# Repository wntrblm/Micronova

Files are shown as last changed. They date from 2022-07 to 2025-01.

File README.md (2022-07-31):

# Winterbloom Micronova

Micronova is a small Eurorack power supply.

More details available at https://winterbloom.com/shop/micronova

## Repository layout

This repository contains the hardware design files and user guide for Micronova:

- **hardware/** contains the hardware design files for the board. These are all created using KiCAD.
- **user_guide/** contains the user's guide source files. These are written in Markdown and published using MkDocs.

## License and contributing

Micronova is open-source hardware and software, however, licensing a project like this is a little complicated. Please take a chance to review the [LICENSE](LICENSE.md) file.

We welcome contributions! Please read our [Code of Conduct](CODE_OF_CONDUCT.md) first.

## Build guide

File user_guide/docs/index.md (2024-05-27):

# Manual

[Micronova](https://winterbloom.com/shop/micronova) is a tiny but mighty Eurorack power supply. It is our love letter to the DIY ethic of the Eurorack community. It packs a lot of useful little features into a small frame and it's perfect for custom rack builds.

[TOC]

## Specifications

An illustration of Micronova

* Available [assembled](https://winterbloom.com/shop/micronova) or as a [kit](https://winterbloom.com/shop/micronova-kit)
* A tiny `100mm x 30mm` board with `M3` mounting holes
* Provides `+12V @ 1A`, `-12V @ 300mA`, and `+5V @ 500mA`
* Includes two 16-pin Eurorack power headers
* Requires a `15V to 20V` **center positive** DC power supply
* Multiple units can be daisy chained
* Reverse-polarity, over-current, and over-temperature protection
* Optional `4 HP` [front entry kit](https://winterbloom.com/shop/micronova-front-entry-kit)
* Optional [busboard](https://winterbloom.com/shop/micronova-busboard)
* [ModularGrid page](https://www.modulargrid.net/e/winterbloom-micronova)

## Getting support and help

We want you to have a wonderful experience with your power supply. If you need help or run into problems, please reach out to us. [Email] is the best way for product issues, whereas [Discord] and [GitHub][github issues] are great for getting advice and help on how to customize your module.

-   Send us [an email][email]
-   File a bug [on GitHub][github issues]
-   Reach out on the [Discord][discord]

[github issues]: https://github.com/wntrblm/Micronova/issues
[discord]: https://discord.gg/UpfqghQ
[email]: mailto:support@winterbloom.com

## Safety

Always use caution when working with electricity. While Micronova does not use mains power directly and operates on relatively low voltages (`-12V to 20V DC`), there is always risk. Never add or remove downstream devices or modify power connections while the system is powered on. Make sure to use an [appropriate AC to DC power supply](#powering-micronova) and to stay within the specified [power limits](#power-limits). Use high-quality cables and appropriately sized wires when making connections.

Micronova includes some protection features:

- It can withstand at least `30V` of reverse polarity on the power inputs
- It has transient voltage suppression on the power inputs
- It has a polyfuse to limit current during a short circuit fault
- It has independent over-current, short circuit, and over-temperature protection on each of the downstream power rails

These protection features do not avert all risks involved with operating a power supply. Micronova can still experience dangerous faults from unexpected events. Improper usage significantly increases the possibility of electric shock and fire. **Always use caution**.

## Powering Micronova

Micronova requires a `15 to 20V DC` power supply that can provide **at least** `1A`. Micronova has multiple, *interconnected* power input connections. It can be powered using one of the two DC barrel jacks or one of the two screw terminal blocks on the upper side of the board.

An illustration of Micronova highlighting the power input connection

!!! warning
    Never connect more than one upstream power supply at a time to Micronova. The multiple DC jacks and screw terminals for [daisy chaining](#daisy-chaining) multiple Micronova units to a single upstream supply. Only **one** upstream power supply should be connected. Connecting multiple upstream power supplies can result in irreversible damage, electric shock, and fire.

In most cases, you'll want to use one of the DC barrel jacks. Both Micronova and the optional [front entry panel](#front-entry-kit) have DC barrel jacks, and either of the two jacks will work. They accept plugs that have a `2.1mm` inner diameter and a `5.5mm` outer diameter. The plug should be **center positive**.

Illustration of DC barrel jack and polarity

These AC to DC power supplies are recommended if you're planning to use the DC barrel jacks:

* Mean Well [GST60A15-P1J](https://www.digikey.com/en/products/detail/mean-well-usa-inc/GST60A15-P1J/7703713) which provides `15V @ 4A (60W)`, enough to power about four Micronovas.
* Mean Well [GST40A15-P1J](https://www.digikey.com/en/products/detail/mean-well-usa-inc/GST40A15-P1J/7703705) which provides `15V @ 2.6A (40W)`, enough to power two or three Micronovas.
* Mean Well [GST25A15-P1J](https://www.digikey.com/en/products/detail/mean-well-usa-inc/GST25A15-P1J/7703649) which provides `15V @ 1.6A (25W)`, enough to power one Micronova.

All of these power supplies are rated for international use and require a separate [IEC C13 cord](https://en.wikipedia.org/wiki/IEC_60320#C13/C14_coupler) to connect to your wall outlet. These cords are incredibly common and often used with computers, monitors, and professional audio and video equipment and should be readily available from local retailers.

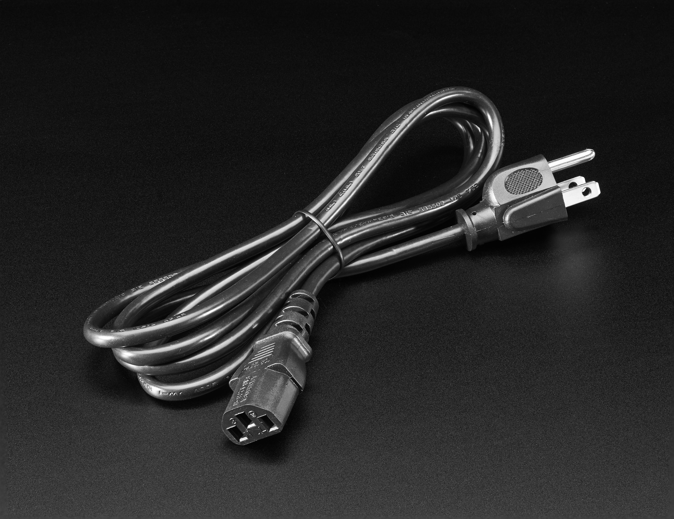
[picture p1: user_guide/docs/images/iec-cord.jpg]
Photo of an IEC C13 cord, photo from Adafruit Industries


If you need help finding a power supply or want to double check compatibility before purchasing, please [reach out to us](mailto:support@winterbloom.com).

In some advanced or unusual racks, you may want to power Micronova through its screw terminals. This might be the case if you're using a large DC power supply such as Mean Well's [RS series](https://www.digikey.com/en/products/detail/mean-well-usa-inc/RS-150-15/7706170). Ensure that the power supply's voltage output is between `15V and 20V`. You can use either of the two screw terminal blocks on the upper side of the board- just not the one labeled `switch`. Connect the power supply to Micronova using appropriately sized hook up wire (`20 or 22 AWG` stranded is recommended).

Illustration of Micronova powered using the screw terminals

## Connecting modules

Connect your modules to Micronova using either *16-to-10* pin IDC cables or *16-to-16* pin IDC cables.

<div class="columns">
    <div class="column">
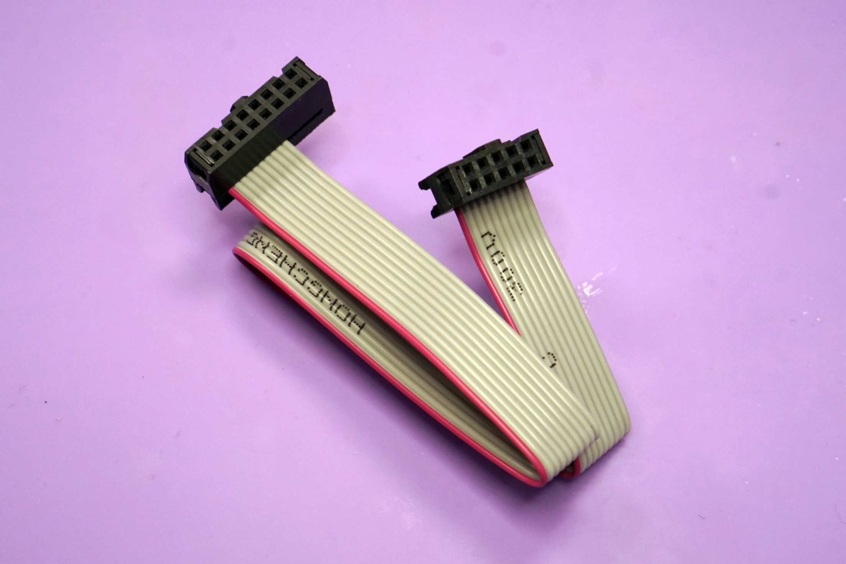
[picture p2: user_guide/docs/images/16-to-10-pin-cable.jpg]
Photo of a 16-to-10 pin IDC cable
        
    </div>
    <div class="column">
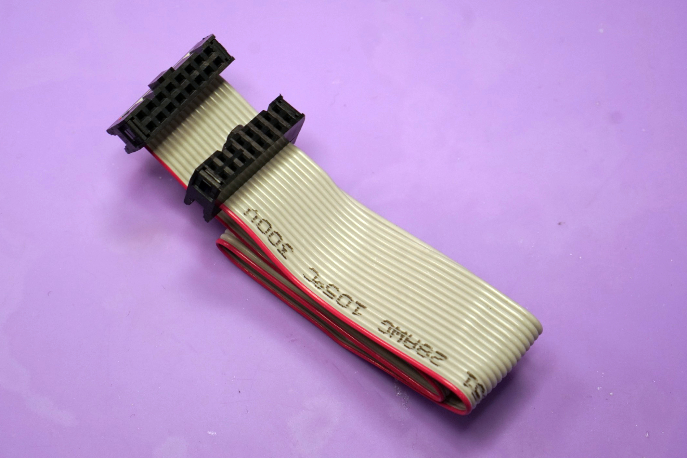
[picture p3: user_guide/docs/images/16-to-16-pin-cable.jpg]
Photo of a 16-to-16 pin IDC cable
        
    </div>
</div>

Be careful to note the polarity of the cable and the connectors on your modules. Polarity indication on modules varies from manufacturer to manufacturer, but most note the side that the red stripe (`-12V`) should be on.

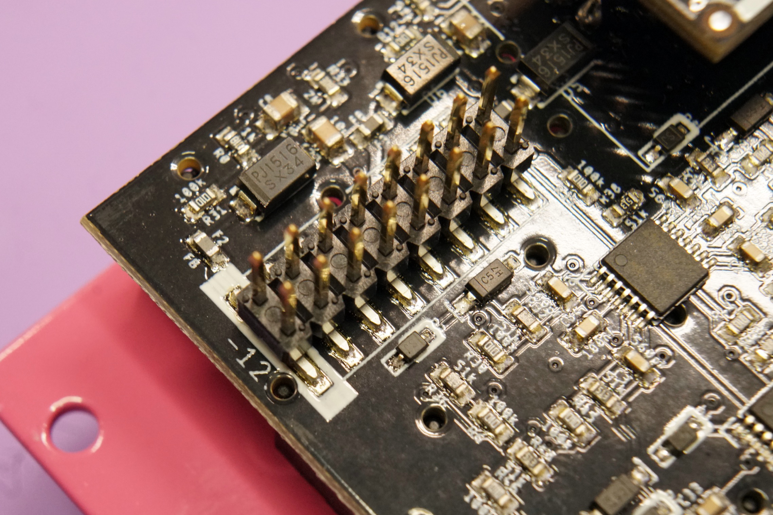
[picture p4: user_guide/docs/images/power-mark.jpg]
Photo of a module indicating power cable polarity


Micronova uses keyed headers so it shouldn't be normally possible to connect power cables backwards on that end.

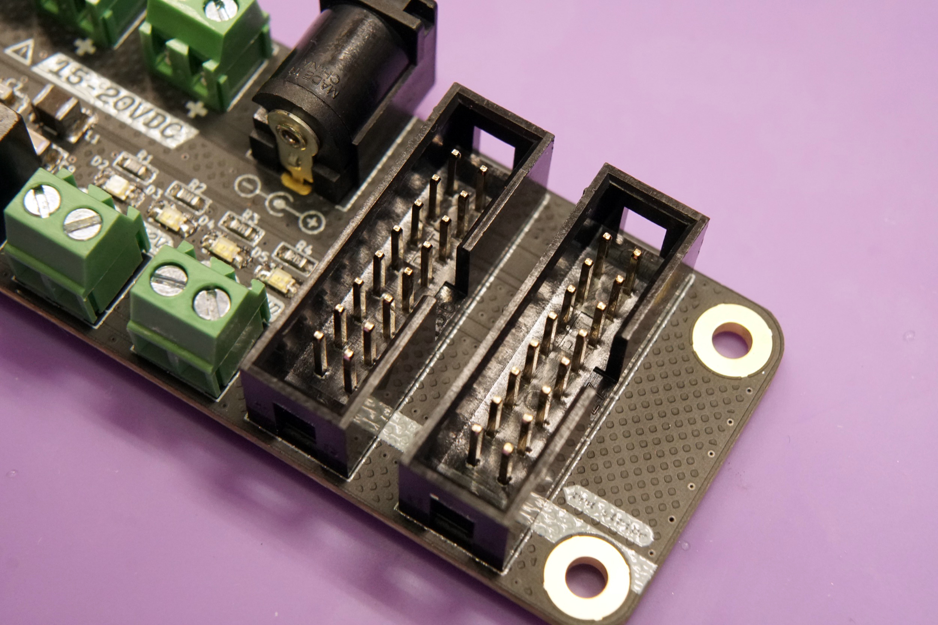
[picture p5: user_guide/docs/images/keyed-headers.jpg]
Photo of Micronova's keyed headers


If you'd like to power more than two modules, you can use a [Busboard](#busboard) or a [flying bus cable].

[flying bus cable]: https://www.thonk.co.uk/shop/bus-cables/

## Power limits

Micronova has limits on how much power it can provide to downstream modules:

- +12V rail: `1A`
- -12V rail: `300mA`
- +5V rail: `500mA`

When connecting multiple modules make sure that the overall current draw does not exceed these limits. Check with each module's manual or manufacturer to determine the current required. [Modulargrid] is also a valueable resource for estimating your system's power requirements. If your set up requires more power than a single Micronova can provide, you can [daisy chain](#daisy-chaining) multiple units.

!!! Warning
    Overloading Micronova can cause irreversible damage to Micronova and connected modules. While Micronova has over-current protection on each rail, the voltage drop-out that occurs when this protection is activated can still cause damage in rare cases.

There are a few ways you can check to make sure that you're within Micronova's limits. The first, and easiest, is to check the four LEDs on the board. They should all be illuminated and three of them should be roughly the same brightness, with the one near the `5V` label being slightly dimmer. Any LEDs that are not illuminated or are very faint indicate an issue with your setup. The photo below shows a correctly functioning unit.

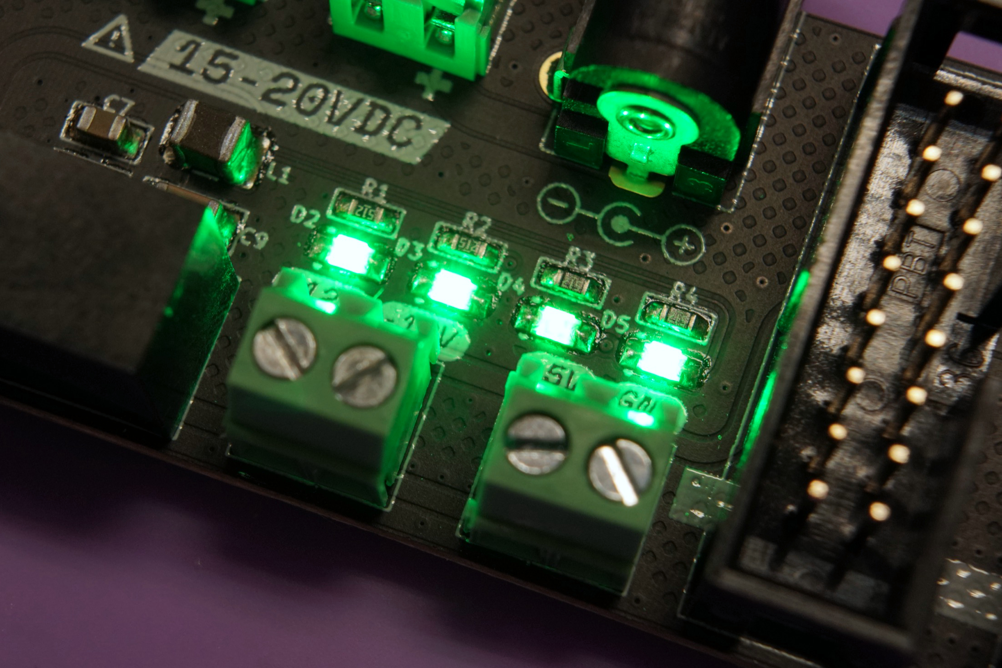
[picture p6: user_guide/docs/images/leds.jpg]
Photo of Micronova's LEDs


The second way is to check the temperature of Micronova's DC-DC converters. These are the three black boxes on the lower-left of the board. You can use a touchless thermometer, thermal camera, or touch the top of them with your finger. It is normal for them to be slightly warm but excessive heat means that Micronova is overloaded.

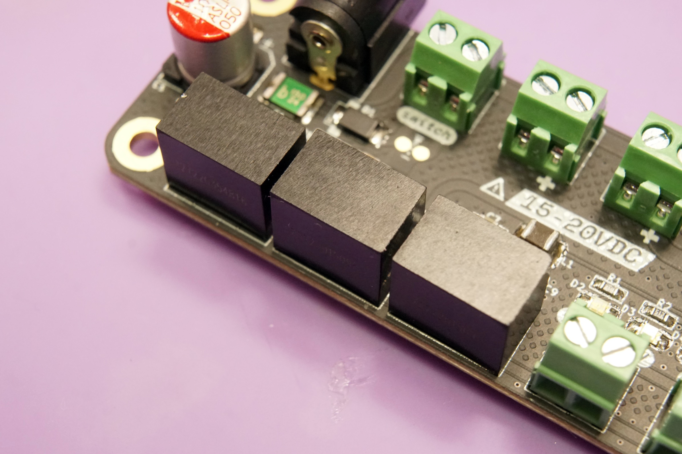
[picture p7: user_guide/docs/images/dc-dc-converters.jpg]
Photo of highlighting Micronova's DC-DC converters


[Modulargrid]: https://modulargrid.net

## Busboard

Micronova's two power outputs can be expanded using the [optional busboard](https://winterbloom.com/shop/micronova-busboard). You'll need to connect Micronova to the busboard using the included 16 pin IDC cable.

Illustration of Micronova and the busboard connected together

When connecting multiple modules, make sure to stay within Micronova's [power limits](#power-limits). If you need more power than one Micronova can provide, you can [daisy chain](#daisy-chaining) two or more units.

## Daisy chaining

You can power multiple Micronova units from a single DC power supply. If the Micronova units are in separate cases, you can connect them together using a [DC jumper cable]:

Illustration of two units connected with a jumper cable

If you have more than one unit within a single case, you can connect them together using the screw terminal blocks:

Illustration of two units connected using the screw terminal blocks

You can use any combination of the DC jacks and screw terminals to daisy chain **as long as there is only one power supply**. Make sure your power supply can provide enough power to satisfy the current demand of the Micronova units. A good rule of thumb is that you need `1A` to `2A` for each Micronova.

[DC jumper cable]: https://www.thonk.co.uk/shop/right-angle-barrel/

## Power switch

In some cases you may want to add a power switch to Micronova, such as cases where it's hard to unplug or reach the power supply. There are a few options.

First, if you're using the [front entry kit](#front-entry-kit) there's a power switch on there, so you're all set!

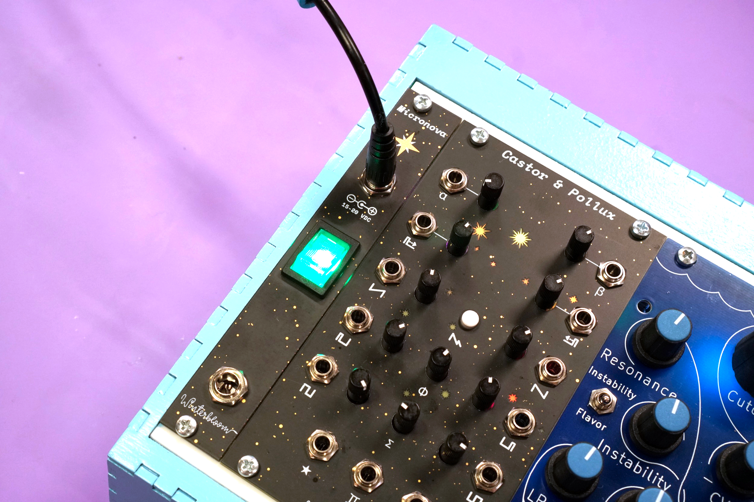
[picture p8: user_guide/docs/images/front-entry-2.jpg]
Photo of the front entry kit


Second, you can use an [in-line DC power switch]. This is connected between your AC to DC power supply and Micronova's DC barrel jack. This is useful for small cases where it's easy to reach the power cable and helps reduce wear on the power cable since you don't have to constantly plug and unplug it.

Illustration of Micronova with an in-line DC power switch

[in-line DC power switch]: https://www.adafruit.com/product/1125

Lastly, you can wire a switch to Micronova's `switch` screw terminal block. This is useful in cases where the power cable is not easily accessible or you're powering Micronova through a large DC power supply. We recommend a switch like the [E-Switch EG5448-ND]. If you get an illuminated switch, make sure the LED can handle `15-20V`.

You'll need to wire each terminal of the switch to the terminal block as shown:

Illustration of wiring a switch to Micronova's switch terminal block

You'll also need to sever the copper trace beneath the switch terminal block.

Illustration of the switch terminal's copper connection

The trace is shown in red. Use a sharp utility knife or razor blade and carefully cut along the dot lines. There is extra empty space around the trace to make it easier to cut without damaging anything.

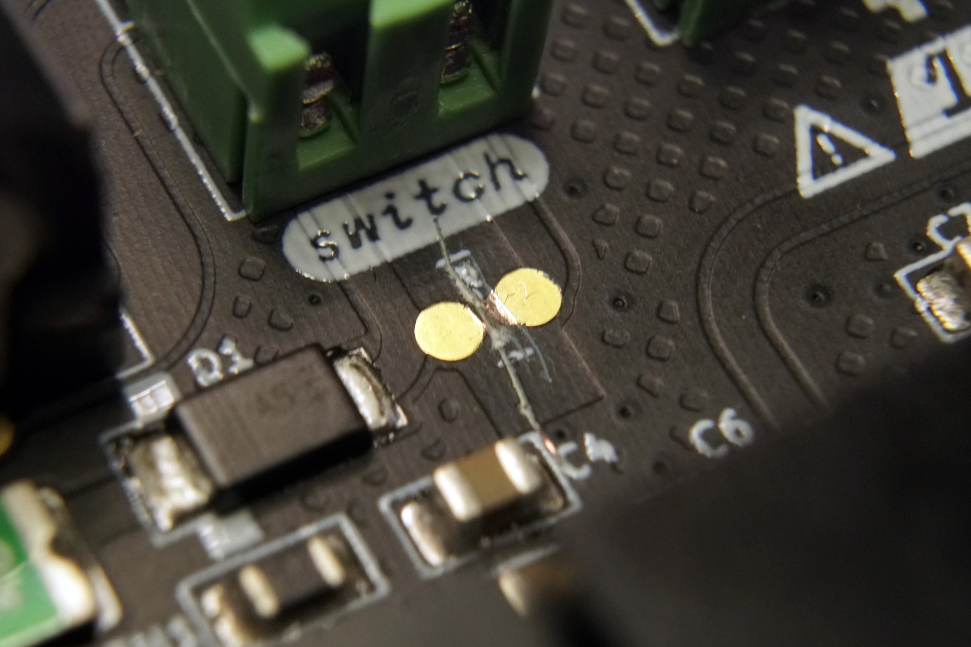
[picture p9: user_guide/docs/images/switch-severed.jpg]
Photo of the trace severed


If you change your mind later and no longer need the switch, you can either place a jumper wire between the two terminals on the terminal block or solder the two pads next to the severed trace together.

[E-Switch EG5448-ND]: https://www.digikey.com/en/products/detail/e-switch/R1973ABLKGILGF3/3778047

## Output terminals

In addition to the two Eurorack 16-pin power headers, Micronova can provide downstream power through the two screw terminals located on the lower side of the board.

Illustration of Micronova's downstream power terminals

Always be aware of Micronova's [power limits](#power-limits) when connecting downstream devices.

## Front entry kit

If you prefer connecting your case's power supply through the front, the [optional front entry kit] provides a `4 HP` panel with two DC barrel jacks and an illuminated power switch.

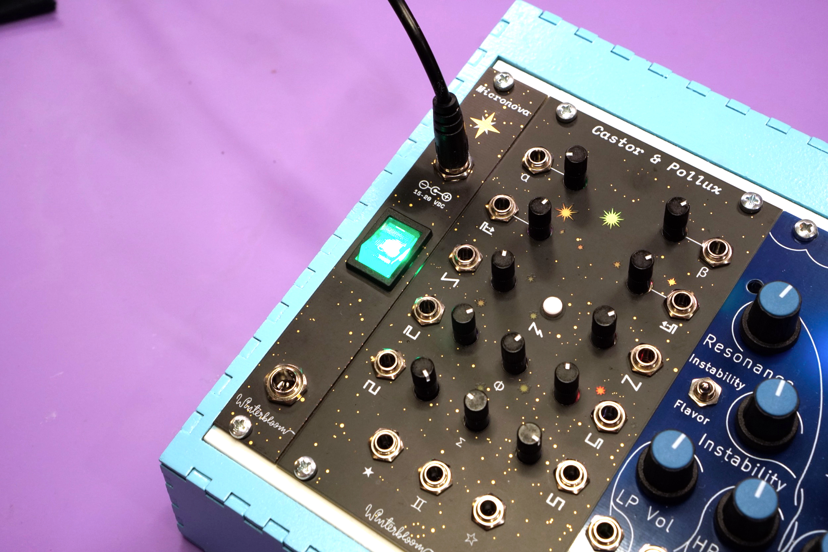
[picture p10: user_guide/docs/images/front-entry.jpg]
Photo of the front entry kit


This is only available as a kit, please refer to the [build guide](build.md#front-entry-kit) for instructions on how to assemble and connect the front entry kit.

[optional front entry kit]: https://winterbloom.com/shop/micronova-front-entry-kit

## Dimensions

If you'd like to physically mount your Micronova in your case, the following dimensions may be useful.

An illustration of Micronova's dimensions

You can [download the SVG] and you can also refer to the [KiCAD] files for the [board's hardware design].

[download the SVG]: images/micronova-dimensions.svg
[KiCAD]: https://kicad.org
[board's hardware design]: https://github.com/wntrblm/Micronova/tree/main/hardware/board

## Open source hardware & software

Micronova is completely open source and hacking is encouraged.

The [hardware designs] are available under the permissive [CERN-OHL-P v2] and is designed using [KiCAD] which is free and open-source. You can open the hardware files using KiCAD or you can [check out a PDF of the schematic][schematic].

Open Source Hardware Association mark Micronova is [certified open source hardware](https://certification.oshwa.org/us002124.html)

Micronova has been used in the following projects:

* [Cornicopia](https://github.com/tpcarlson/synth-diy/tree/main/cornucopia) by [@tpcarlson](https://github.com/tpcarlson)

If you make something based on Micronova, please [let us know](#getting-support-and-help)! We'd love to add your project here.

[hardware designs]: https://github.com/wntrblm/Micronova/tree/main/hardware
[CERN-OHL-P v2]: https://cern-ohl.web.cern.ch/
[KiCAD]: https://kicad.org/
[schematic]: https://github.com/wntrblm/Micronova/tree/main/hardware/board/board.pdf

## Warranty, disclaimers, and limits

Micronova is a subcomponent used by the customer as part of a larger overall system. Because Winterbloom does not have any control over other subcomponents within the customer's system (including, but not limited to, the AC to DC power supply used to provide power to Micronova and any modules powered by Micronova), Winterbloom bears no responsibility for any damage caused to other subcomponents.

Micronova units purchased from Winterbloom have a warranty of six months from the date of purchase. This warranty covers any manufacturing defects in the module. It does not cover damage from due to incorrect handling, storage, or power, overvoltage events, or modifications.

Please [contact us](mailto:support@winterbloom.com) if you are experiencing issues with your unit. Units returned under warranty will either be refunded, replaced, or repaired at our discretion. You will be responsible for the cost of returning the module to Winterbloom.

Because Eurorack has a vast number of possible combinations of power supplies, modules, cases, and accessories, it is impossible for us to guarantee compatibility with every possible configuration. We make a reasonable effort to test our products with several power supplies, cases, and other modules.

We encourage tinkering, however, we will not refund, repair, or replace any products that have been modified.

We have stress tested Micronova under the following conditions. These are provided for reference only; we do not guarantee that that the product will function under these conditions or continue to function if exposed to these circumstances.

* Continuous run time of at least `48 hours`
* Overvoltage at power input up to `24V`
* Undervoltage at power input down to `13V`
* Reverse voltage at power input up to `30V`
* Short circuit at power outputs triggers thermal overload
* `+12V` power output up to `2A` before thermal overload
* `-12V` power output up to `1A` before thermal overload
* `5V` power output up to `1A` before thermal overload
* `1 hour` thermal overload recoverable
* Polyfuse trip time under `5 seconds`
* Polyfuse recovery time under `1 minute`

## Acknowledgments and thanks

Micronova would not be possible without the support of Winterbloom's incredible community.

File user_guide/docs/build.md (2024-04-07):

---
title: Kit build guide
---

# Build

Welcome to the build guide for Micronova's DIY kit. We hope you have a great time putting your Micronova together and a wonderful time using it.

Please **read all instructions** thoroughly before starting. If you have questions or run into trouble please reach out to us on [discord] or drop us [an email][email].

Some soldering experience is helpful but not required. If it's your first time soldering we recommend reading through [Adafruit's guide to excellent soldering](https://learn.adafruit.com/adafruit-guide-excellent-soldering).

This is a **beginner level** kit. Some soldering experience is helpful but not required, though we recommend practicing on another project first. We also have some slightly easier kits available, such as our [Helium kit]. Even if you've got some experience, we recommend taking a look at [Adafruit's guide to excellent soldering][adafruit soldering guide].

This build takes around **one hour** to complete.

[TOC]

[discord]: https://discord.gg/UpfqghQ
[email]: mailto:support@winterbloom.com
[Helium kit]: https://winterbloom.com/shop/helium-kit
[adafruit soldering guide]: https://learn.adafruit.com/adafruit-guide-excellent-soldering

## Tools required

Before you begin, make sure that you've got:

-   Safety glasses. Yes, **really**. A pair like [these][safety glasses] are fine.
-   Proper ventilation, like this [small filtered fan](https://a.co/d/eUfPCRO).
-   A **temperature-controlled** soldering iron, like this [Hakko] or the [Pinecil]. It is very important to use a temperature-controlled iron, since unregulated irons can easily get hot enough to damage components. You should set your iron temperature based on your solder manufacturer's recommendations.
-   Solder. We recommend [Adafruit's SAC305 solder][adafruit solder] or [Kester 275 K100LD].
-   A small flat head screwdriver, like [this one][small screwdriver].

!!! question "Flux"
    We suggest using solder with "no clean" flux. If you use a different kind of flux, be sure to carefully clean the flux residue off based on the guidelines provided by the manufacturer of your solder. Take special care with the LEDs and potentiometers, as they can be damaged by water and flux cleaners.

[safety glasses]: https://a.co/d/dMXvPP6
[tweezers]: https://www.adafruit.com/product/422
[Hakko]: https://www.adafruit.com/product/1204
[Pinecil]: https://pine64.com/product/pinecil-smart-mini-portable-soldering-iron/
[adafruit solder]: https://www.adafruit.com/product/734
[Kester 275 K100LD]: https://www.kester.com/products/product/275-flux-cored-wire
[flux pen]: https://www.sra-solder.com/sra-312-no-clean-flux-pen-refillable

## Kit contents

Your kit should contain the following items. If any are missing please email us at support@winterbloom.com.

<winter-image-map src="../images/kit.svg">
    <winter-image-map-item id="board">Mainboard</winter-image-map-item>
    <winter-image-map-item id="_12v">12V DC-DC converters</winter-image-map-item>
    <winter-image-map-item id="_5v">5V DC-DC converter</winter-image-map-item>
    <winter-image-map-item id="idc">16 pin IDC headers</winter-image-map-item>
    <winter-image-map-item id="barrel">DC barrel jacks</winter-image-map-item>
    <winter-image-map-item id="terminal">Screw terminal blocks</winter-image-map-item>
</winter-image-map>

- (1) Mainboard
- (2) DC barrel jacks
- (5) 2-pin screw terminal blocks
- (2) 16 pin shielded IDC headers
- (2) 12V DC-DC converters
- (1) 5V DC-DC converter

## Screw terminals

The first step is placing and soldering the five 2-pin screw terminal blocks.

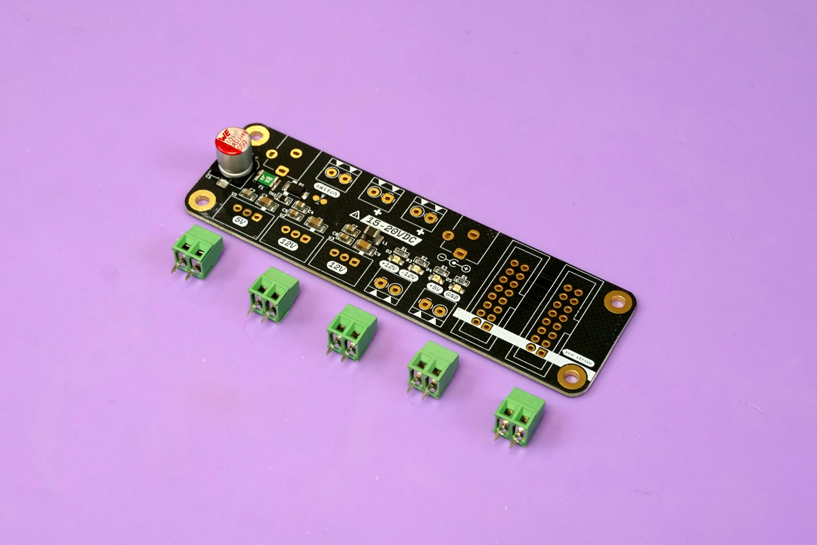
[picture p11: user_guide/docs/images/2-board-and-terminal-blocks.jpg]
Photo of the board and five screw terminal blocks


It's easiest to solder one terminal block at a time. Place a terminal block on the front side of the board, taking care to place it so that the terminal openings face *outward* and match up with the triangles on the board.

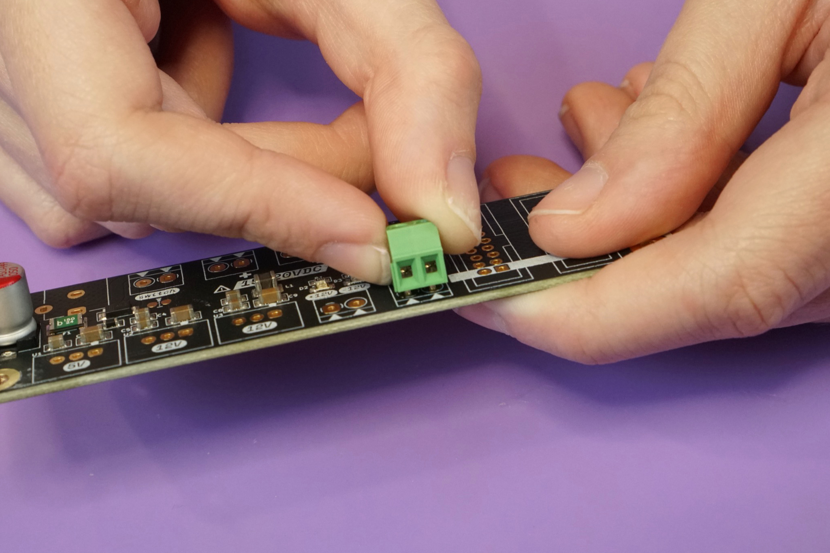
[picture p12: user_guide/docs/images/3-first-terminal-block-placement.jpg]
Photo with one of the terminal blocks placed onto the board


Hold the terminal block in place and flip the board over. It's okay if the terminal block isn't completely flush against the board, as long as the legs are through the holes.

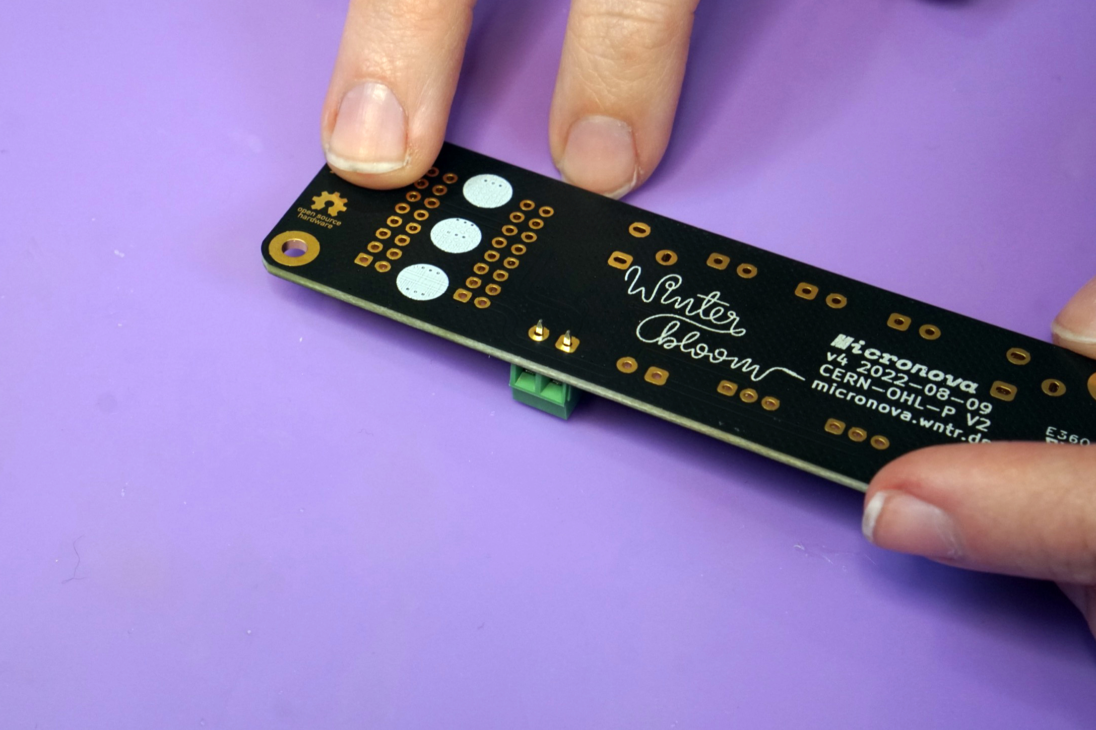
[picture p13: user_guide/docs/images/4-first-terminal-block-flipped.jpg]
Photo with the board flipped over and the terminal block's legs poking through the board


Solder one leg of the terminal block to hold it in place.

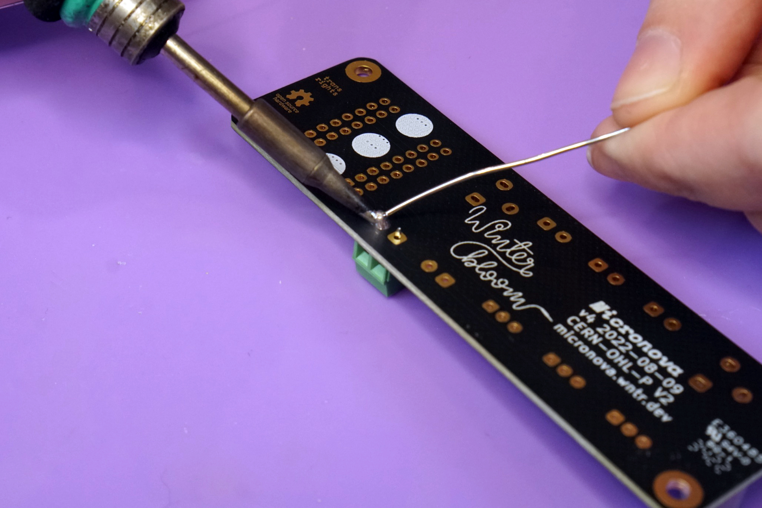
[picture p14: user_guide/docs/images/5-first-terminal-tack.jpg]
Photo with one leg of the terminal block soldered to the board


Lift the board and use your iron to reflow the solder and push the terminal block flush against the board. Wait a few seconds for the joint to solidify before releasing the board.

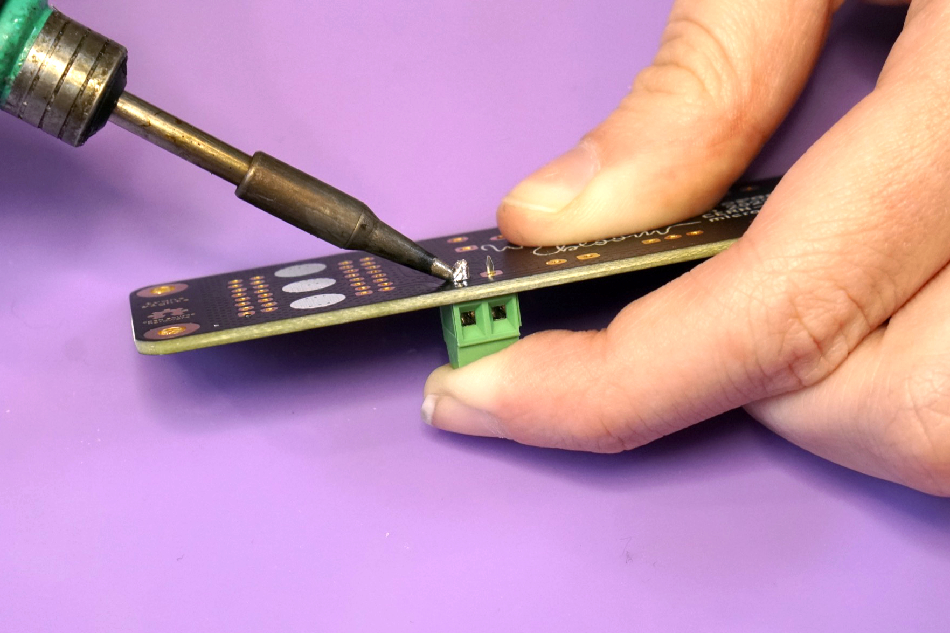
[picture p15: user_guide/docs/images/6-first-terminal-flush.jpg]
Photo with one leg of the terminal block being pushed flush against the board while applying the soldering iron to the joint


With the terminal block now flush against the board, solder the second leg into place.

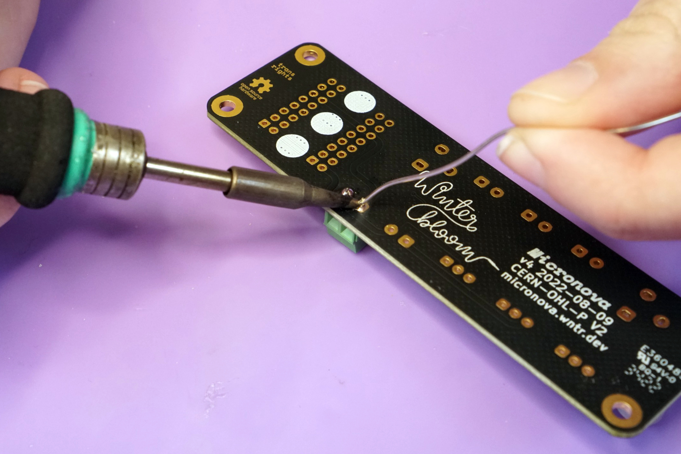
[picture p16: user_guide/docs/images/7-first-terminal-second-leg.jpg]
Photo of the back of the board with both legs of the terminal block soldered


Repeat this process for the four remaining terminal blocks, taking care to align the terminal openings.

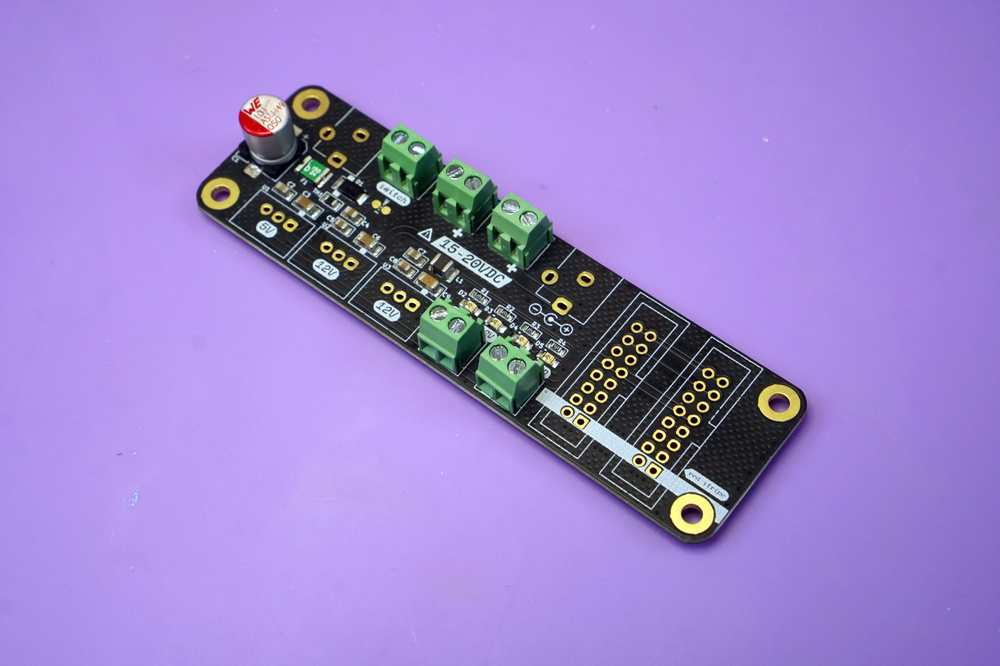
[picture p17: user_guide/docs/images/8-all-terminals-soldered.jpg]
Photo of the board with all terminal blocks soldered


## IDC headers

Your next task is placing and soldering the two 16 pin shielded IDC headers.

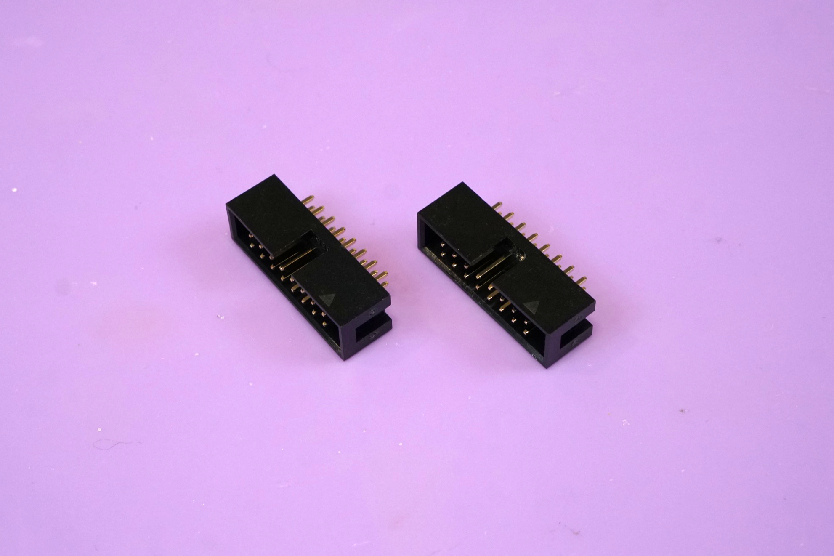
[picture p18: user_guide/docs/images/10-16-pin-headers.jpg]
Photo of the two 16-pin shielded IDC headers


Place both of them on the front side of the board, being careful to align the notch in the header's shield with the drawing on the board. The board is designed to hold on to these headers tightly, so you might have to give a little pressure to push them all the way in.

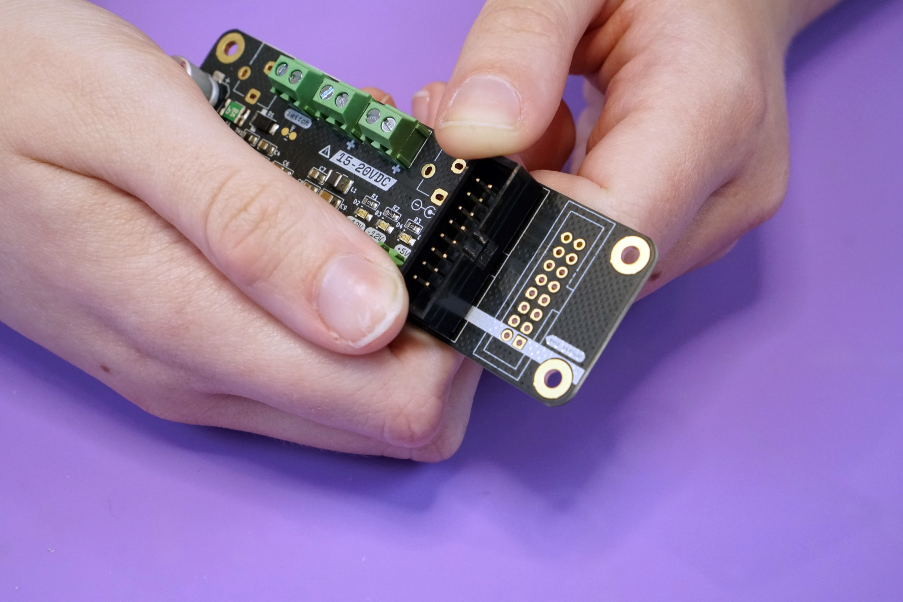
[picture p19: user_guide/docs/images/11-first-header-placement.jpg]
Photo of the first header placed on the front side of the board

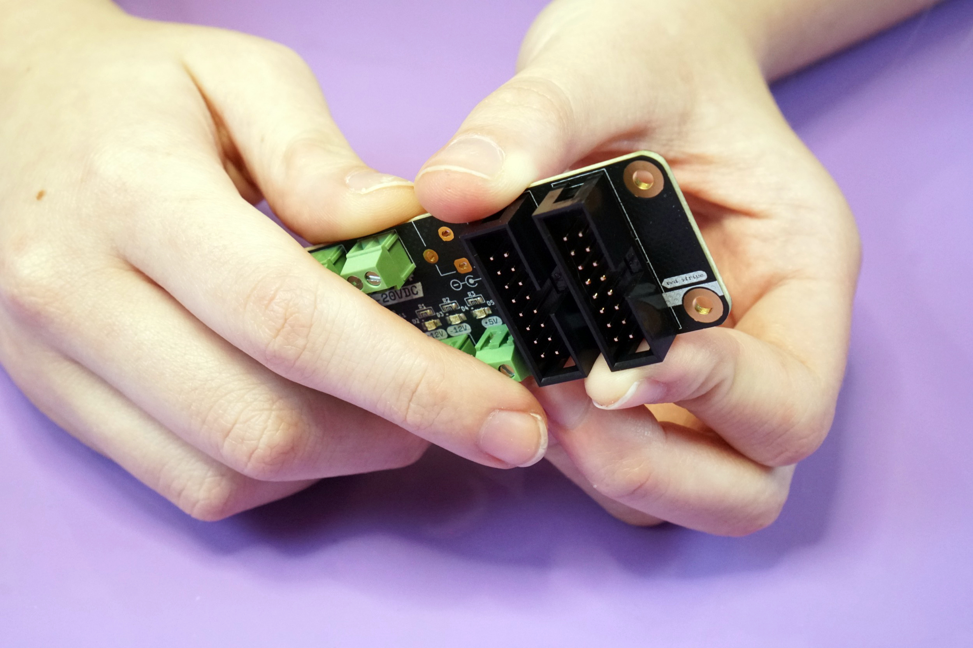
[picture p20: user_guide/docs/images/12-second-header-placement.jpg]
Photo of the second header placed on the front side of the board


Once you have both placed, flip the board over and solder just one pin on each header to tack it in place.

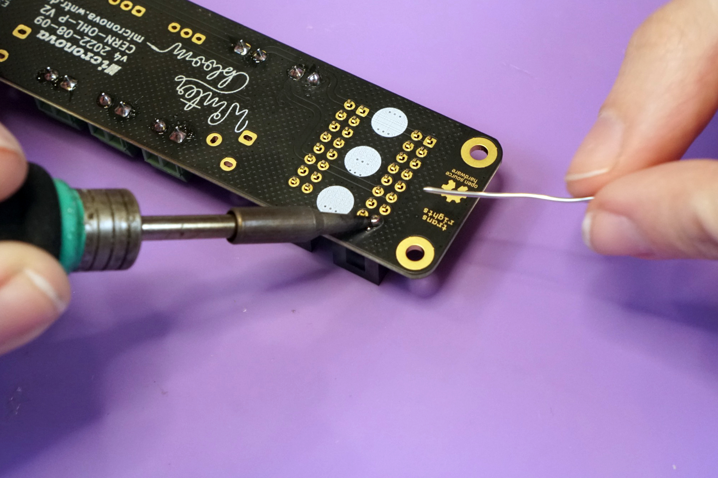
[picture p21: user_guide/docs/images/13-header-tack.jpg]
Photo of one pin on the header soldered to hold the header in place

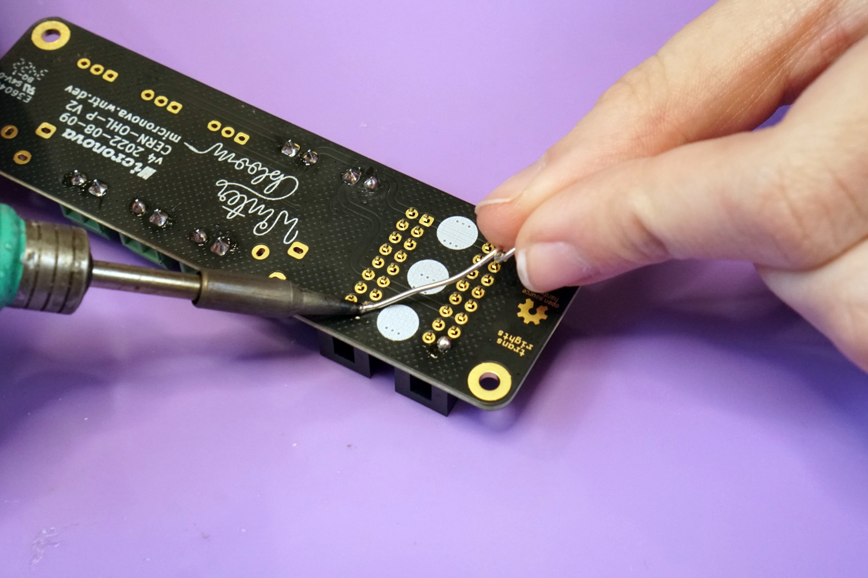
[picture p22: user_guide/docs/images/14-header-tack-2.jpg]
Photo of the second header with one pin soldered to hold it in place


Double check that both headers are completely flush against the board, if they aren't, you can fix them using the same technique you used with the screw terminals. Once you've checked the placement, solder all 16 pins on both headers. You should be able to do them both at the same time, but if you're having trouble feel free to do them one at a time like you did with the terminal blocks.

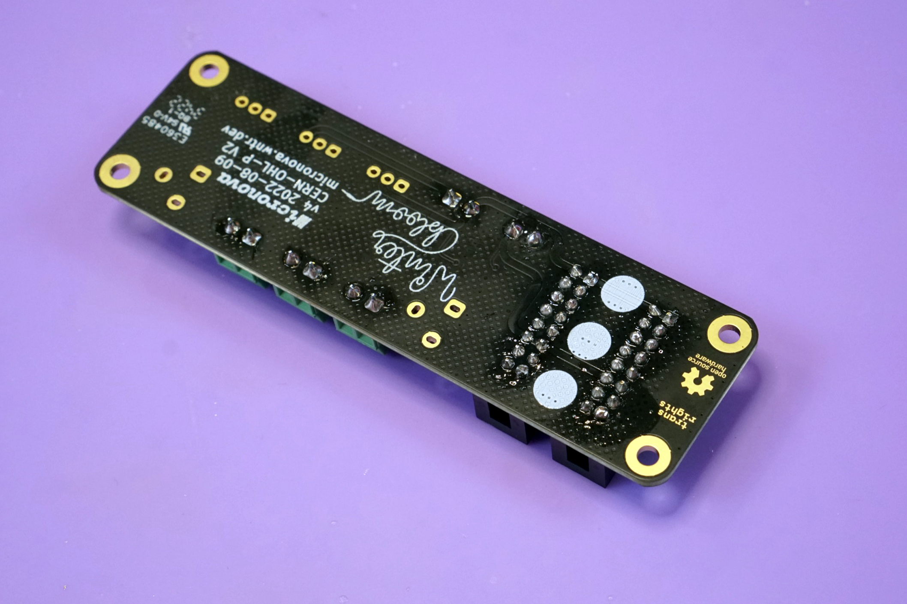
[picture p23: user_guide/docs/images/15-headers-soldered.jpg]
Photo of all of the pins on both headers soldered


## DC barrel jacks

Next up is placing and soldering the two DC barrel jacks.

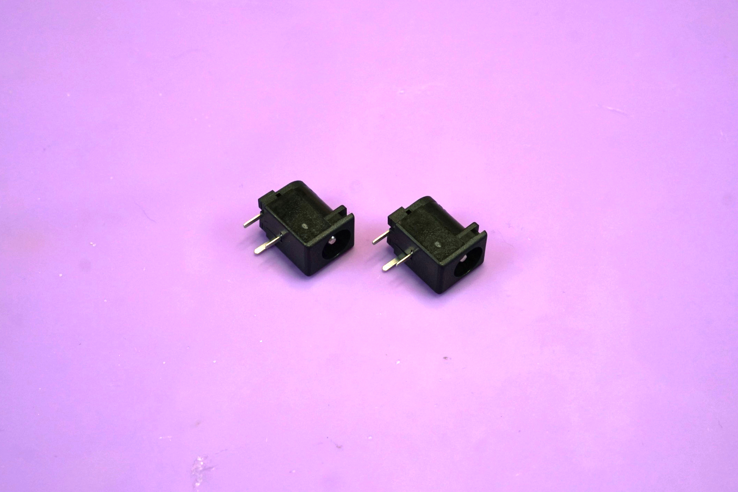
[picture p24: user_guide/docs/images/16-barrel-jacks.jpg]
Photo of the two DC barrel jacks


Similar to the terminal blocks, it's easiest to place these one at a time. Place one on the front side.

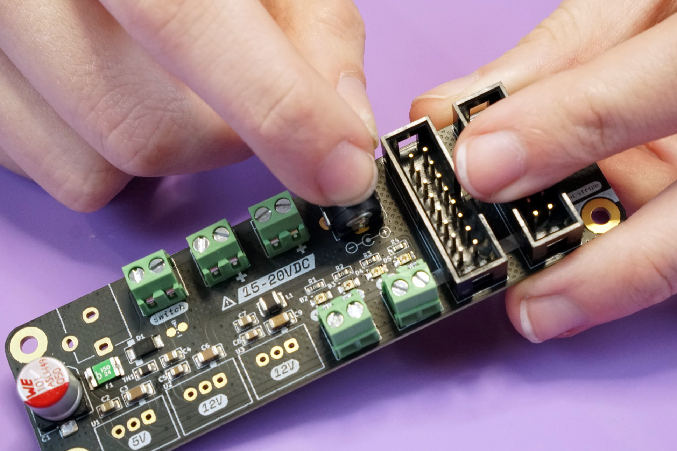
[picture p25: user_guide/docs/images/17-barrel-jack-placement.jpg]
Photo of one barrel jack placed on the front side of the board


Then carefully flip the board over and solder just one leg to hold the barrel jack in place.

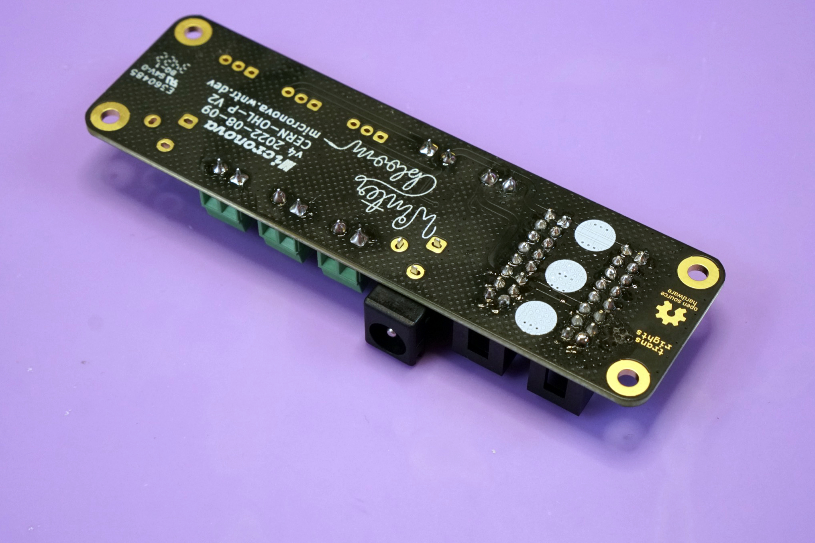
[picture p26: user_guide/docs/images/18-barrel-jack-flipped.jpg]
Photo of the back of the board with the barrel jack legs poking through

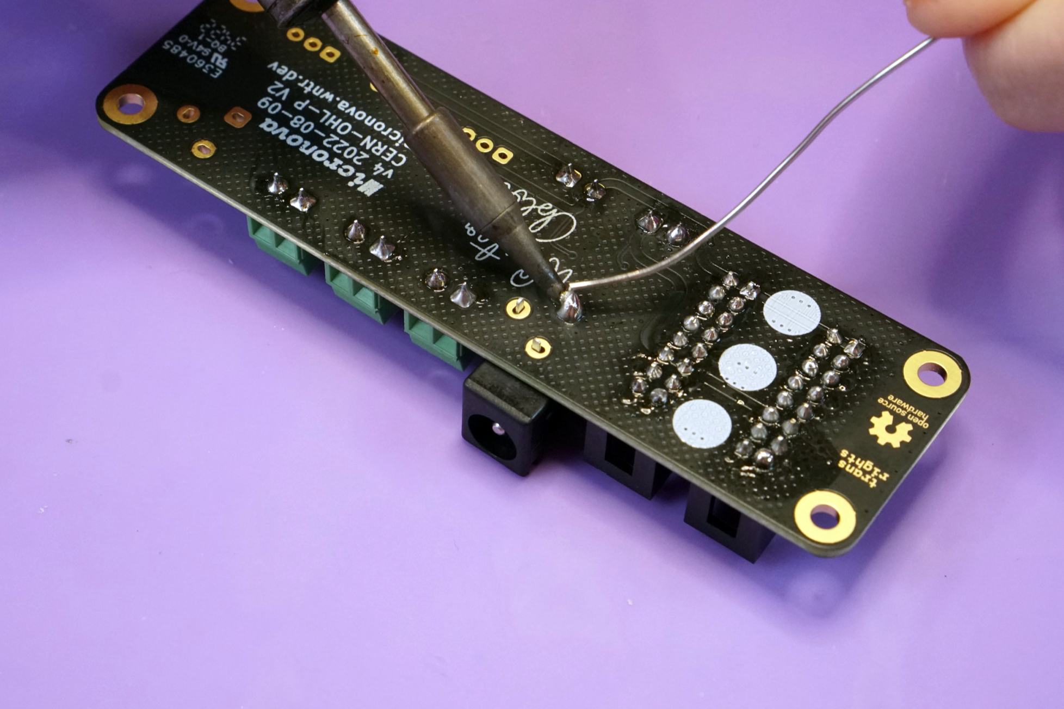
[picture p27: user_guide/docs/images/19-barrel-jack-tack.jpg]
Photo of one pin on the barrel jack soldered


Just as you did with the terminal blocks, lift the board and use your iron to reflow the solder and push the barrel jack flush against the board. Wait a few seconds for the joint to solidify before releasing the board.

With the barrel jack flush and held in place, solder the remaining two legs.

Finally, repeat this process for the second barrel jack.

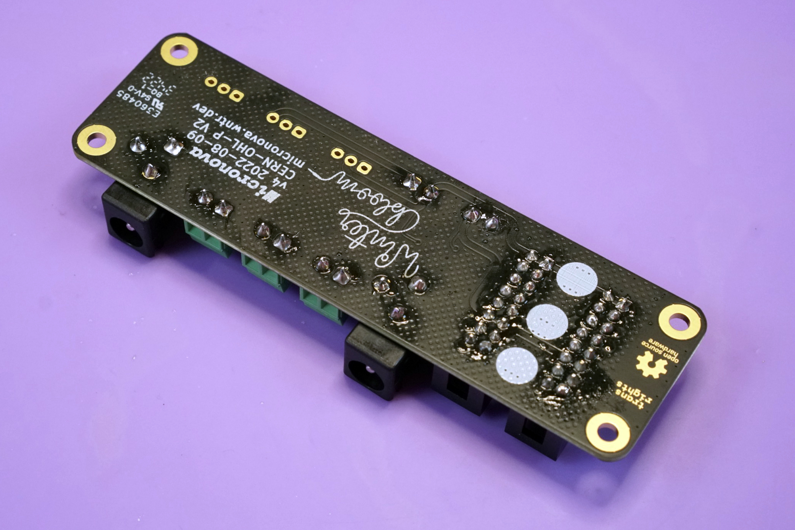
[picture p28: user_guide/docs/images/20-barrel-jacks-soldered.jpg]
Photo of the back of the board with both barrel jacks completely soldered


## DC-DC converters

The last step is to solder the three DC-DC converters. There are two 12V converters and one 5V converter. You'll need to identify them before placing them since they **must** be placed correctly for Micronova to work.

The single 5V converter is slightly smaller and has `VX7805-500` marked on it.

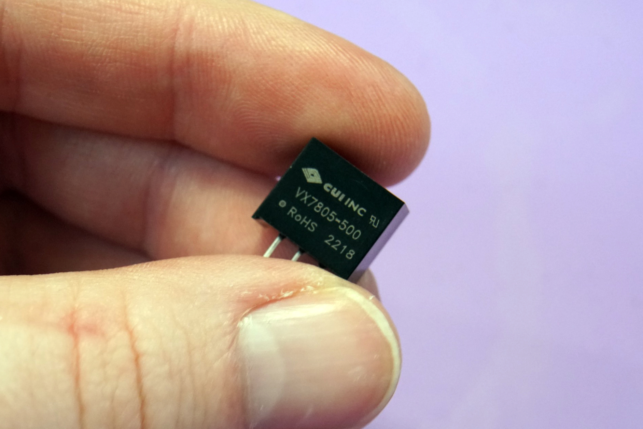
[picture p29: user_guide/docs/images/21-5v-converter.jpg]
Photo of the 5V DC-DC converter


The two 12V converters are slightly larger and has `K7812M-1000R3` marked on it.

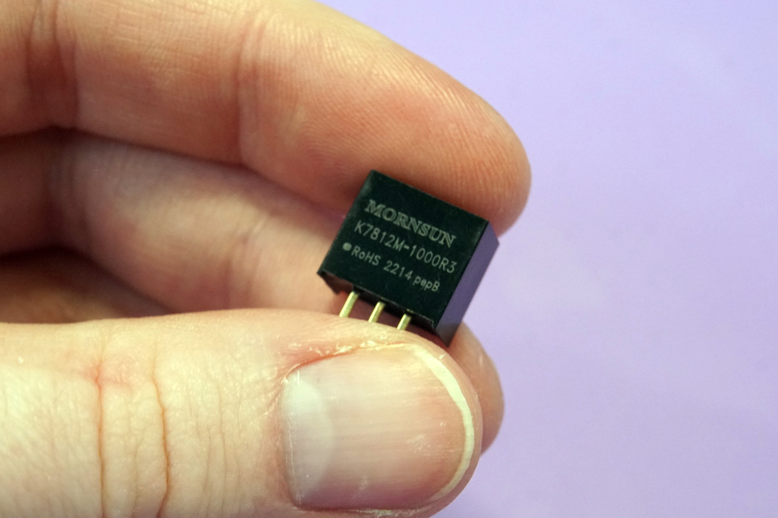
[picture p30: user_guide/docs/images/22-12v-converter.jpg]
Photo of the 12V DC-DC converter


Start by placing the **5V** converter on the front side of the board. It goes in the spot labeled `5V` on the lower left. Make sure the converter is oriented correctly so that it fits nicely within the white rectangle on the board.

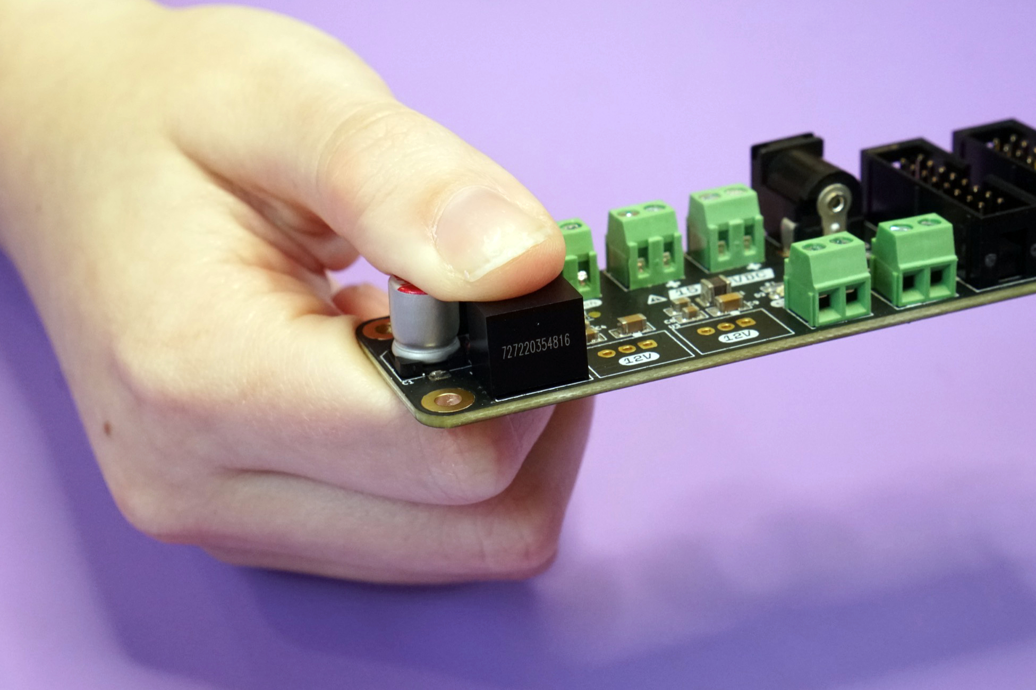
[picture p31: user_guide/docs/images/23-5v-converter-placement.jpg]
Photo of the 5V converter placed onto the front side of the board


Carefully flip the board over and solder one leg to hold the converter in place.

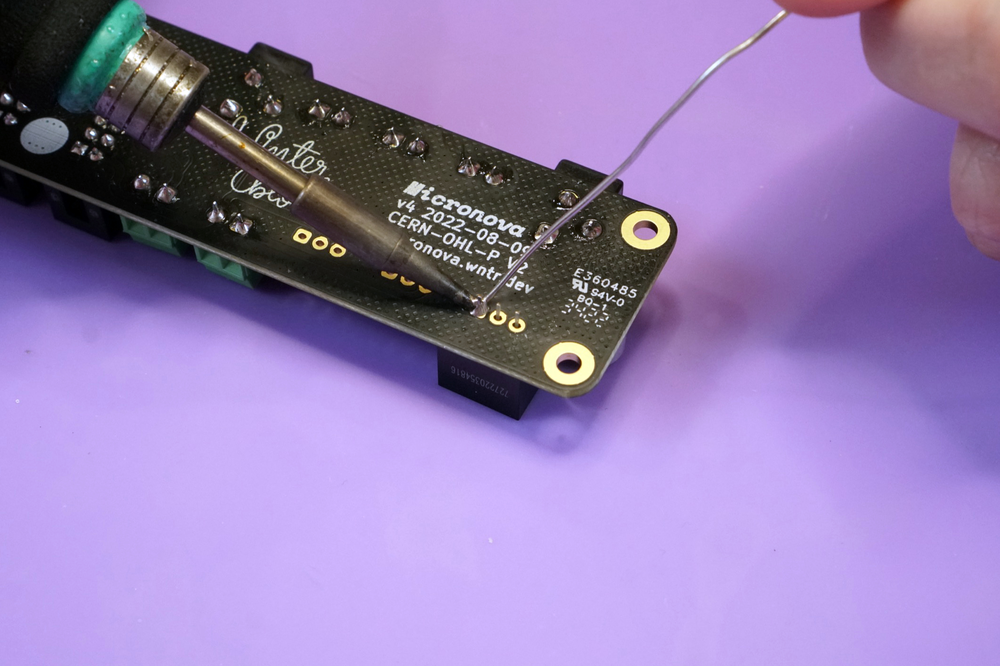
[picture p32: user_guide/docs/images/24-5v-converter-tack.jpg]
Photo of the back of the board with just one left of the 5V converter soldered into place


Using the same technique as the DC barrel jacks and terminal blocks, reflow the solder and push the DC-DC converter flush against the board.

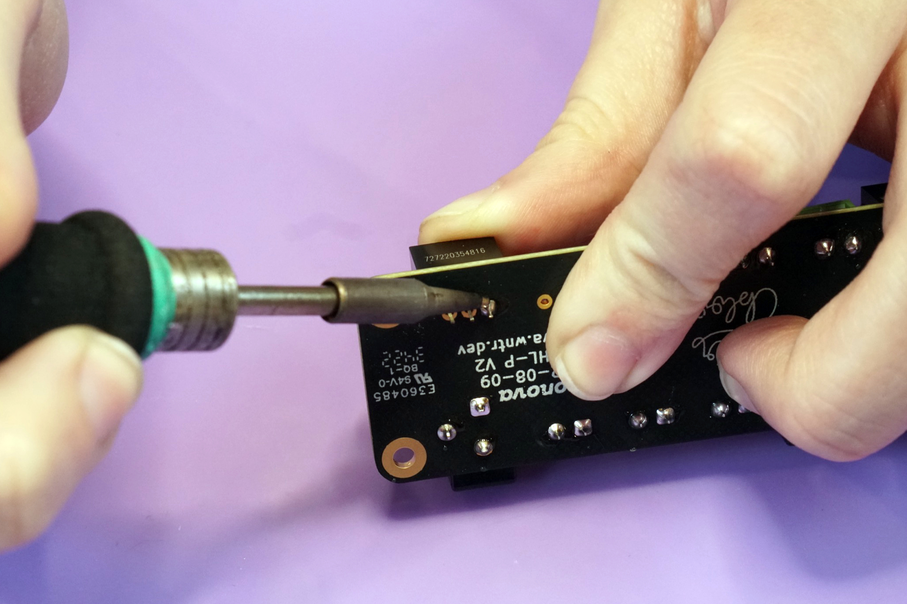
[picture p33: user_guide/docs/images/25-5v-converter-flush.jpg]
Photo of the 5V converter being pushed flush against the board while heat is applied to the solder joint using a soldering iron


Once the DC-DC converter is flush, solder the remaining legs.

Repeat for the two 12V converters. They go into spots adjacent to the 5V converter marked `12V`. Again, make sure that they are oriented to match up with the corresponding white rectangle on the board.

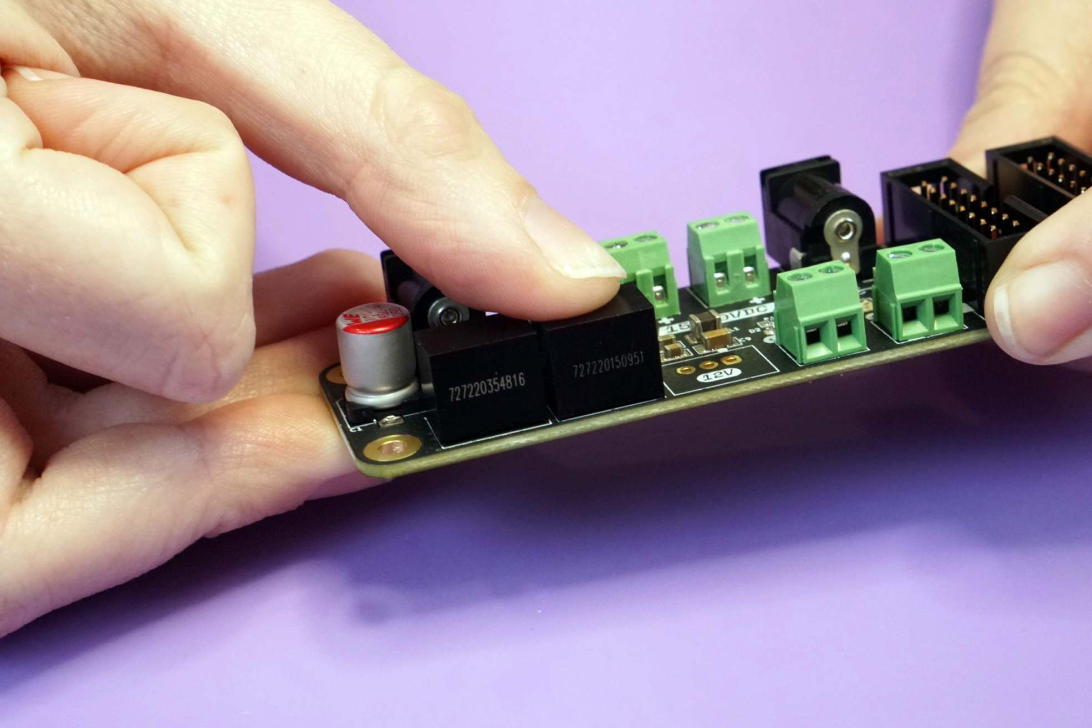
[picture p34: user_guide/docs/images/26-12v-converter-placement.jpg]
Photo of one of the 12V converters placed on the board


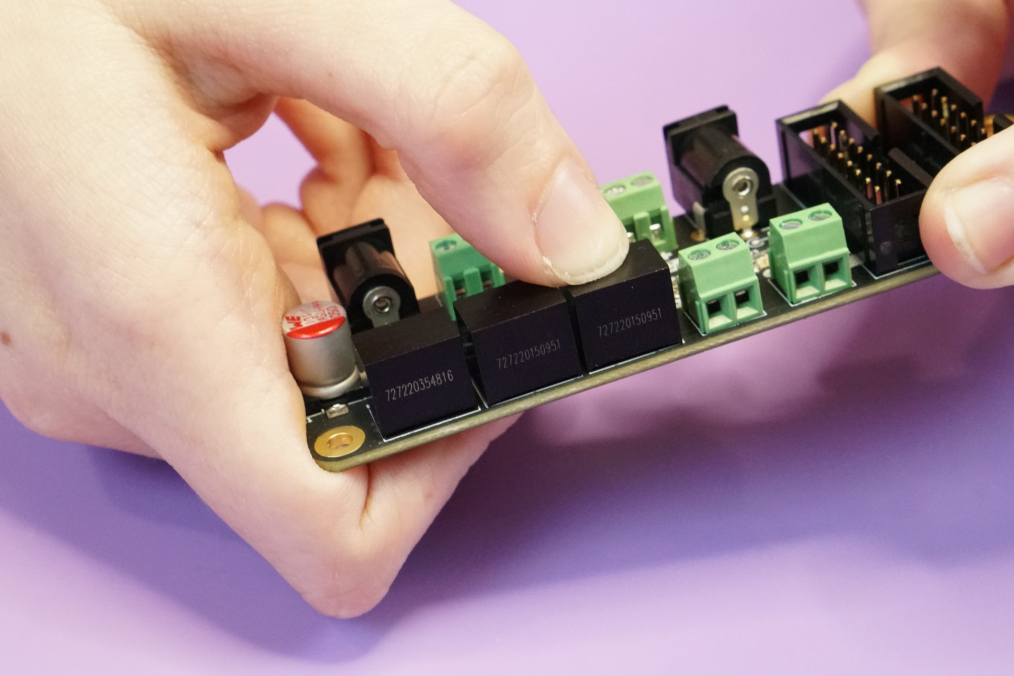
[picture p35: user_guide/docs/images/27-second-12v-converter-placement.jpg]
Photo of the second 12V converter placed on the board


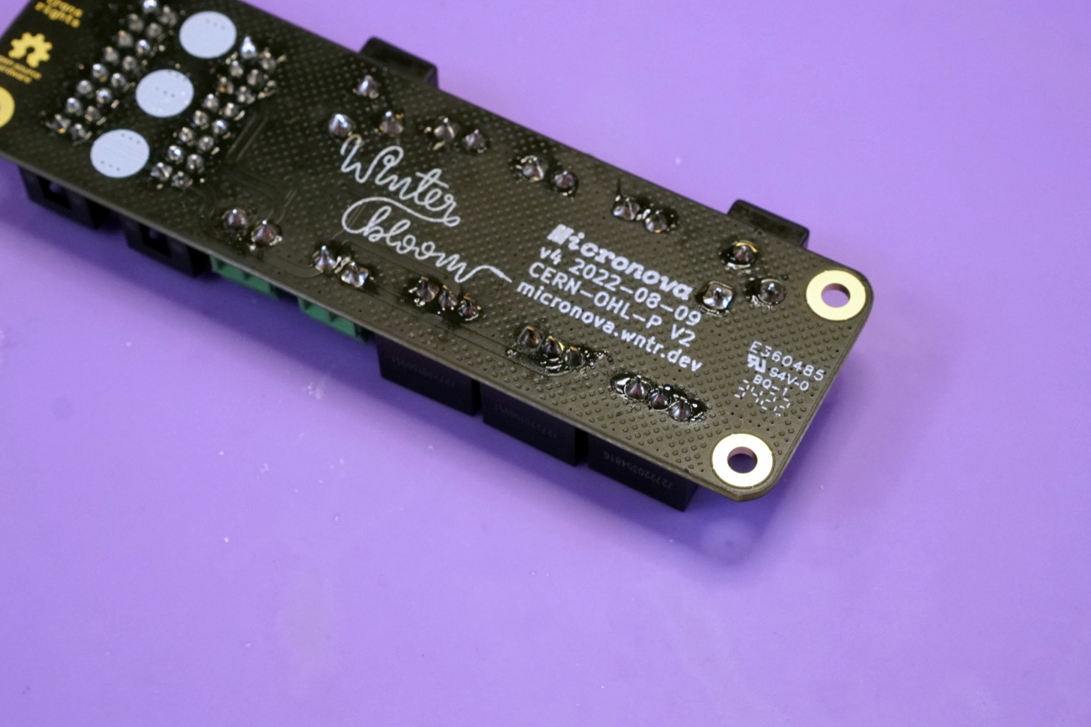
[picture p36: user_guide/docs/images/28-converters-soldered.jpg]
Photo of the back of the board with all of the converters completely soldered


You're all done! If you have a busboard kit or a front entry kit, continue reading. If not, hop down to [the end](#all-done) for some useful links.

## Busboard

The busboard kit adds six additional power headers to your Micronova.

Your busboard kit should contain the following items. If any are missing please email us at support@winterbloom.com.

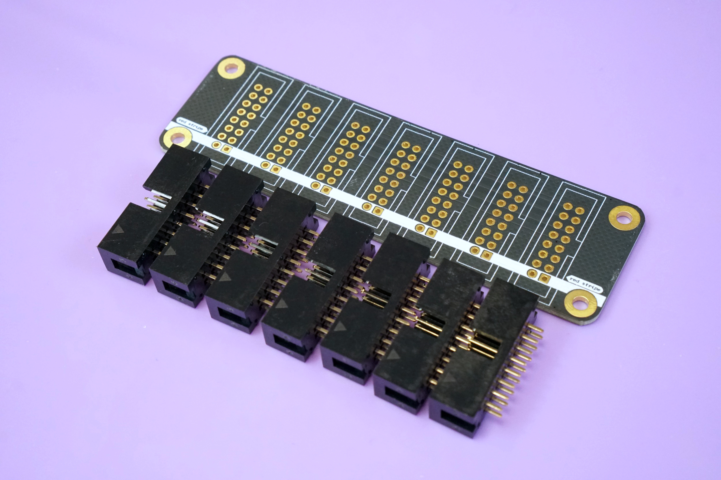
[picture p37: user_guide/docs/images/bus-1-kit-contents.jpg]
Photo of the busboard kit's contents


- (1) Busboard PCB
- (7) 2x8 pin shielded IDC headers
- (1) 16 pin to 16 pin IDC cable (not pictured)

Assembling the busboard kit is fairly straightforward. Start by placing all seven IDC headers on the front side of the board, making sure to align the notch in the header's shield with the drawing on the board. The board is designed to hold on to these headers tightly, so you might have to give a little pressure to push them all the way in.

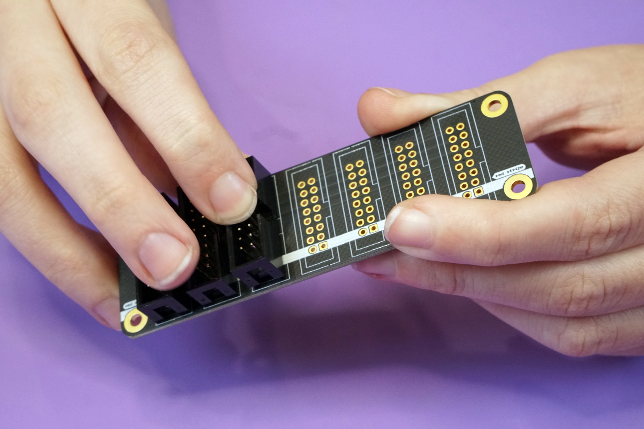
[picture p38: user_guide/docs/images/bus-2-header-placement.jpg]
Photo of three of the headers placed on the front of the board

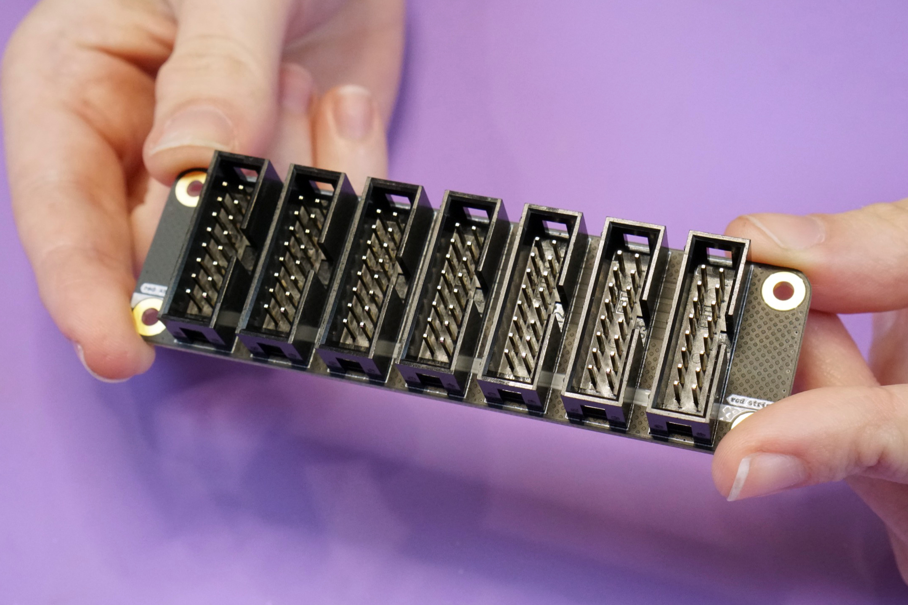
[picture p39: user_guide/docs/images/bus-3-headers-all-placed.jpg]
Photo of all seven headers placed on the front of the board


Flip the board over and solder one pin on each header to tack them into place.

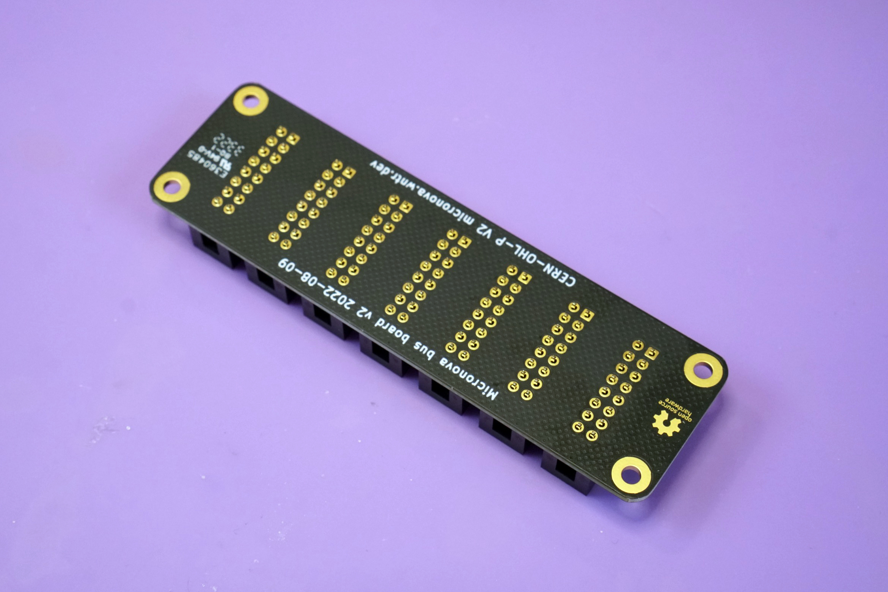
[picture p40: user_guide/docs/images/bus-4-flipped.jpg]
Photo of the back of the board with the legs of all of the headers poking through

Photo of one pin on the first header soldered
Photo of one pin on the second header soldered
Photo of one pin on each header soldered

Make sure that the headers are all flush against the board and adjust if needed by re-heating the solder joints. Once you're sure they're all flush, solder them all in to place.

Photo of all headers completely soldered to the board

That's it! 🙂

## Front entry kit

The front entry kit lets you power your Micronova via a 4hp panel in your rack.

Your front entry kit should contain the following items. If any are missing please email us at support@winterbloom.com.

Photo of the front entry kit's contents

- (1) Front entry panel
- (2) Panel mount DC barrel jacks, including washers and nuts
- (1) Rocker switch
- (2) M3x6 mounting screws (not pictured)

You will need hook up wire to assemble this module. We recommend 20 or 22 AWG stranded wire in red and black.

The first step is to prepare four 13cm (5") lengths of wire- two red, and two black. Strip the sleeve 1cm on both ends.

You also need two lengths of wire that will connect from the front panel to the Micronova board inside your case. Make sure you have enough length to reach and strip the sleeve 1cm on both ends.

Mount the switch in the panel, making sure that the `-` is facing upwards. The panel's switch cutout has a very tight fit, so you may have to compress the plastic springs on the switch to get it to snap into place.

Photo of the rocker switch being placed through the cutout in the panel
Photo of the rocker switch mounted to the panel

Mount the two DC barrel jacks to the panel, placing the washer and nut onto the jack from the front side of the panel.

Photo of the first DC barrel jack placed through the top hole in the panel
Photo of the washer added to the DC barrel jack
Photo of the nut added to the DC barrel jack
Photo of both DC barrel jacks mounted to the panel

Wire the jacks and switch together as shown below, being care to wire the the correct leads on the barrel jacks.

Illustration of the front panel wiring

With everything wired up, give it a quick test by plugging in a power cable and making sure that the switch illuminates when switched on. If it does not illuminate or if it stays illuminated even when off, double-check your wiring **before** continuing.

If everything checks out, mount the panel in your rack.

Photo of the panel placed in a rack

Run the power wires to your Micronova and use the screw terminals to connect them.

Illustration of power connections

## All done

Congratulations! You've finished your very own Micronova!

Now that it's all put together go check out the [User's Guide](index.md) and please show us your work by tweeting at [@wntrblm](https://twitter.com/wntrblm) or tagging [@wntrblm](https://instagram.com/wntrblm) in your instagram post.

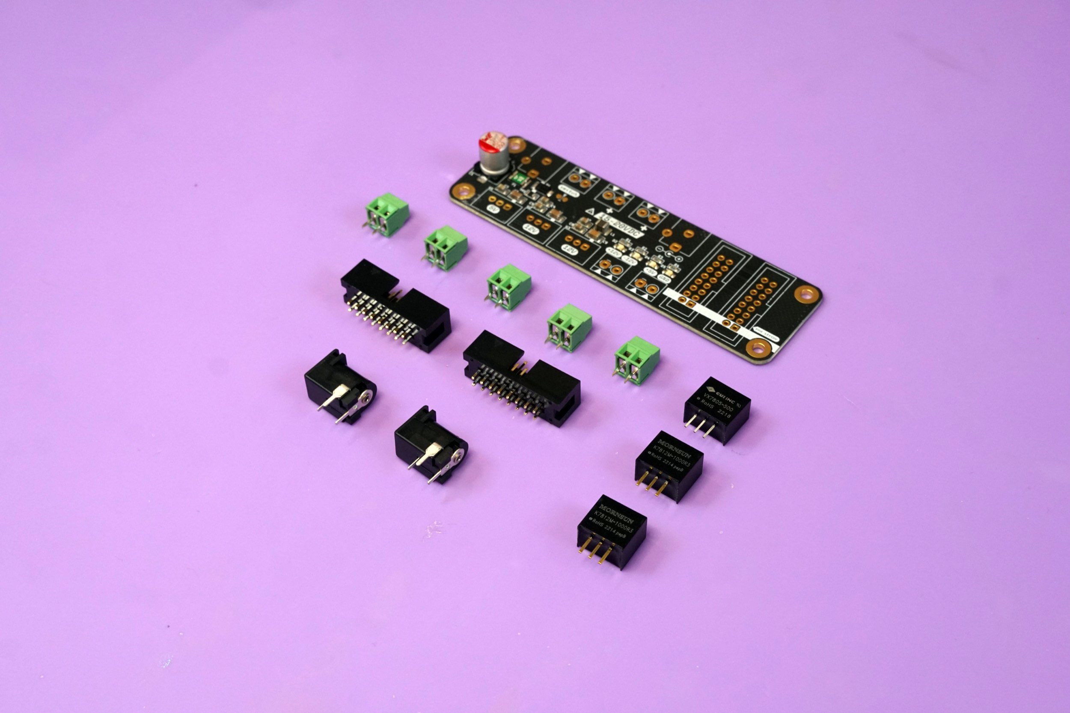
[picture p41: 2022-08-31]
user_guide/docs/images/1-kit-contents-3.jpg

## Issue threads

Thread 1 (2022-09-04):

Possible error in board.pdf

n9jcv, 2022-09-04:
I believe ther is an error in the schematic.  You have a p78e12 for both positive and negative supply.  The pins on the negative supply, 2 and 3 seem to be reversed on the schematic.  I belive pin 3 should be gnd and pin2 is -12v out.

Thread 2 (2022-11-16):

alternatives to VX7805-500?

KeLaiFu, 2022-11-16:
The BOM component VX7805-500 doesn't seem to be available in my country, are there any suggested alternatives?

To my untrained eye, the Recom r-78e5.0-0.5 looks like a good fit, but I'd prefer an expert's opinion before I toast my rack.

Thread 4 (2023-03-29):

docs/build: pin missmatch with switch datasheet

proppy, 2023-03-29:
On the diagram below https://micronova.wntr.dev/build/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 it seems that the switch pins `1` and `1a` should be swapped.

If we refer to `Circuit A SPST Illuminated` of page 5 and `SPST Illuminated PCB Layout` on page 4 of https://sten-eswitch-13110800-production.s3.amazonaws.com/system/asset/product_line/data_sheet/75/R1973.pdf: `positive`  in the schematic needs to be connected to pin `1a` not pin `1` (otherwise the switch will be effectively always be illuminated).

proppy, 2023-03-29:
used a slightly different wiring so that the switch connect on the switch connector and used even when powering the micronova directly.

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

Closed 2023-03-29.

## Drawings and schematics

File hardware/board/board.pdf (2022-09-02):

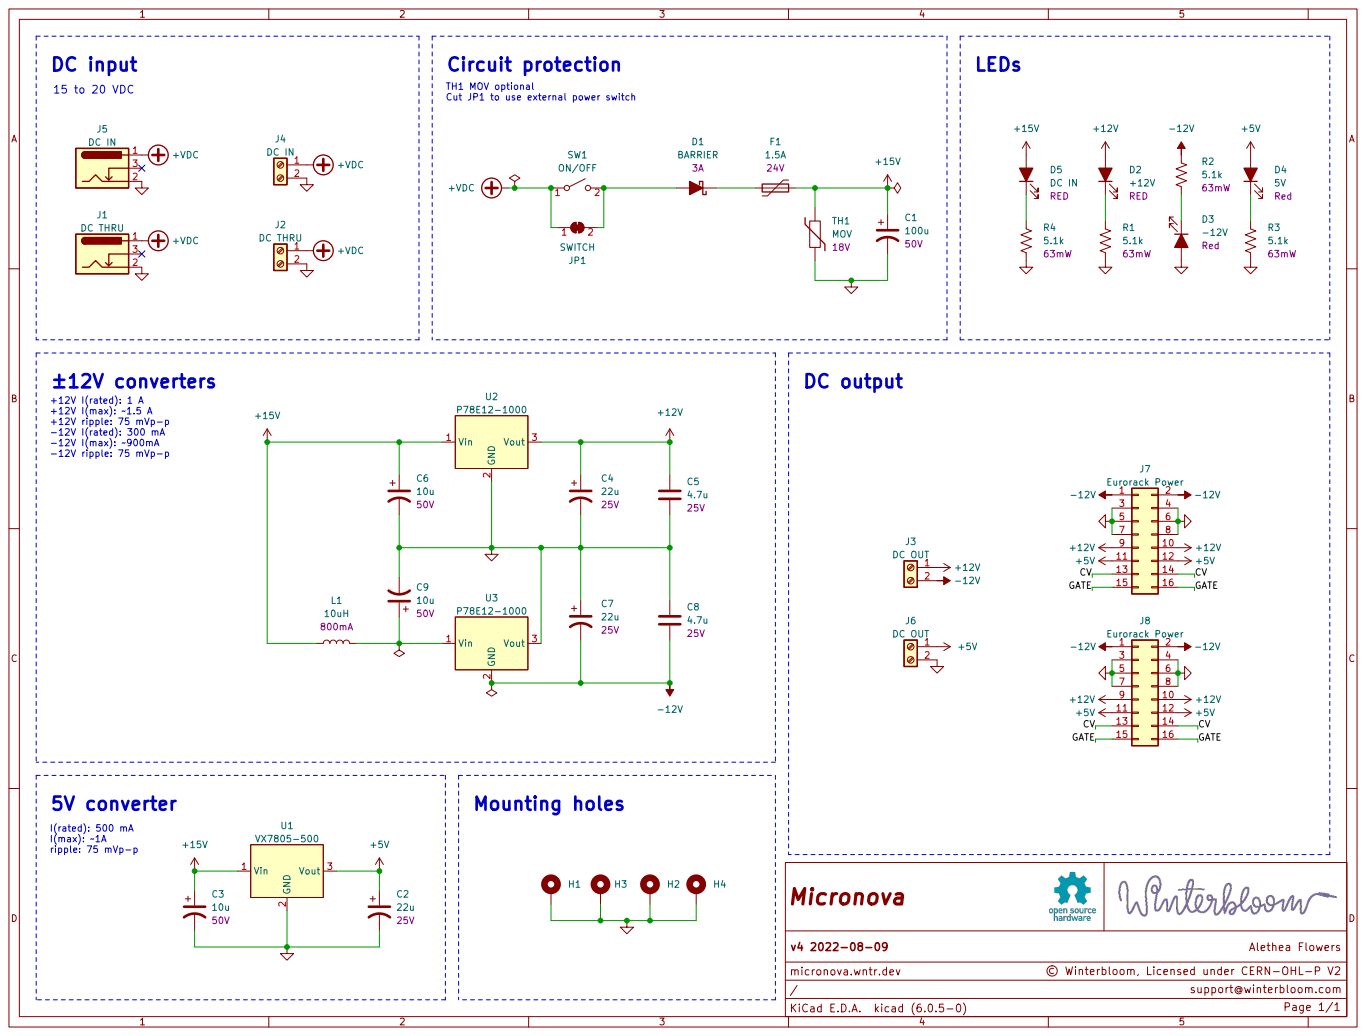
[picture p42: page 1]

TH1 MOV optional
Cut JP1 to use external power switch

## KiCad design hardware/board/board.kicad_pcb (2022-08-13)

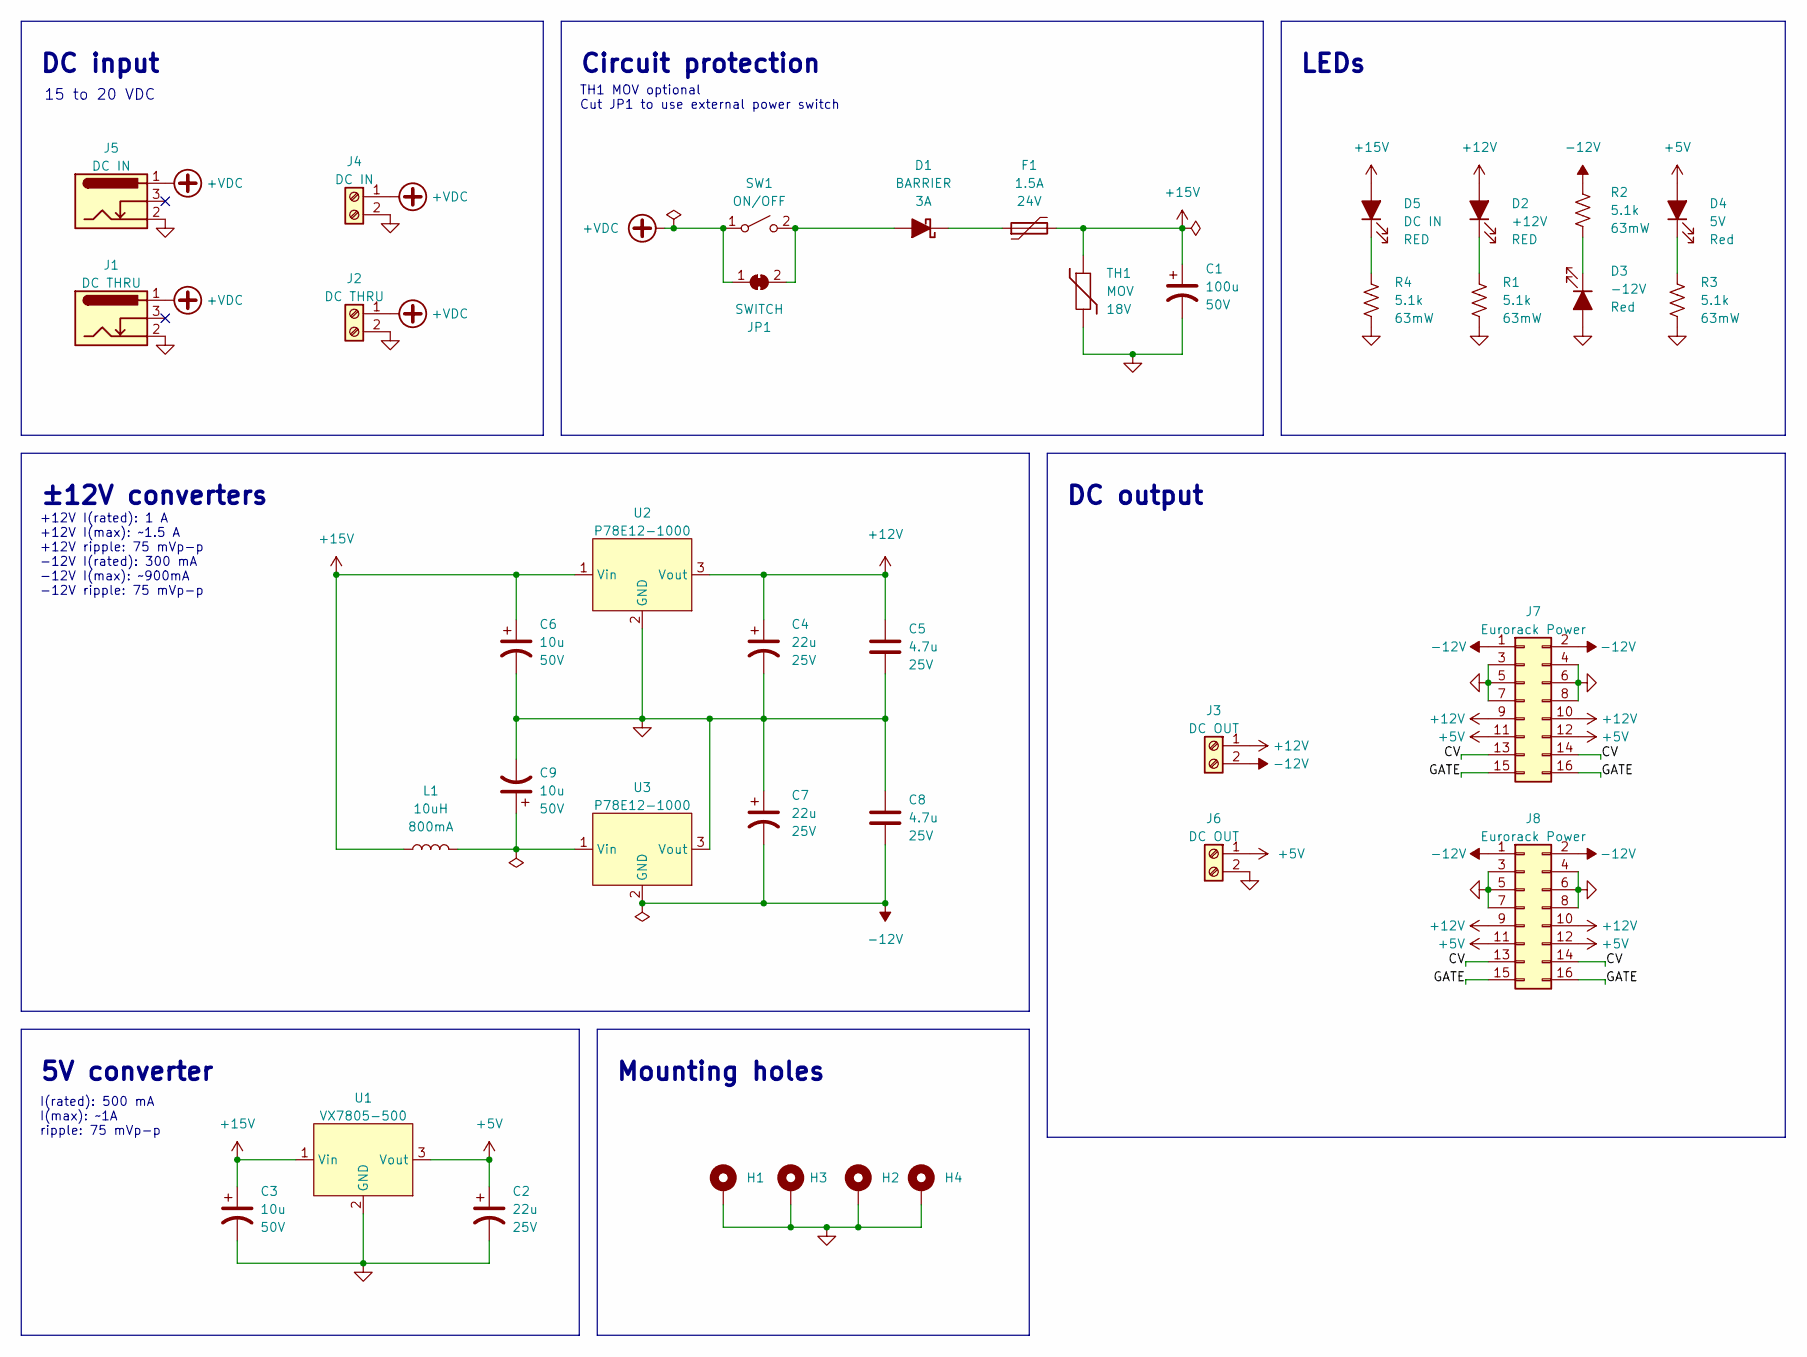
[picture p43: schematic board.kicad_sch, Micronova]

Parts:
C1: 100u; CP_Elec_8x10.5; Rating 50V; mpn 865060653010
C2, C4: 22u; C_0805_HandSolder; Rating 25V
C3, C6, C9: 10u; C_1206_HandSolder; Rating 50V
C5, C8: 4.7u; C_0805_HandSolder; Rating 25V
C7: 22u; C_0805_HandSolder
D1: BARRIER; D_SOD-128; Rating 3A; mpn PMEG3030EP,115
D2: +12V; LED_0805_Kingbright_APT2012; mpn APT2012EC
D3: -12V; LED_0805_Kingbright_APT2012; mpn APT2012EC
D4: 5V; LED_0805_Kingbright_APT2012; mpn APT2012EC
D5: DC IN; LED_0805_Kingbright_APT2012; mpn APT2012EC
F1: 1.5A; R_1812_4532Metric_Pad1.30x3.40mm_HandSolder; Rating 24V; mpn 0ZCG0150BF2C
H1, H2, H3, H4: GND; MountingHole_3mm_Pad
J1: DC THRU; BarrelJack_CUI_PJ-102AH_Horizontal; mpn PJ202-A
J2: DC THRU; TerminalBlock_4UCON_1x02_P3.50mm_Horizontal
J3, J6: DC OUT; TerminalBlock_4UCON_1x02_P3.50mm_Horizontal; mpn 20020327-C021B01LF
J4: DC IN; TerminalBlock_4UCON_1x02_P3.50mm_Horizontal
J5: DC IN; BarrelJack_CUI_PJ-102AH_Horizontal; mpn PJ-102A
J7, J8: Eurorack Power; Eurorack_Power_2x8_Shrouded_Lock; mpn 61201621621
JP1: SWITCH; SolderJumper-2_P1.3mm_Bridged2Bar_RoundedPad1.0x1.5mm
L1: 10uH; L_1210_3225Metric_Pad1.42x2.65mm_HandSolder; Rating 800mA; mpn CBC3225T100KR
R1, R2, R3, R4: 5.1k; R_0603_HandSolder; Rating 63mW; mpn AC0603FR-075K1L
SW1: ON/OFF; TerminalBlock_4UCON_1x02_P3.50mm_Horizontal; mpn 2MS1T1B1M2QES
TH1: MOV; R_0805_HandSolder; Rating 18V; mpn MLVC08V018C360
U1: VX7805-500; Converter_DCDC_CUI_VX78-500_THT; mpn VX7805-500
U2, U3: P78E12-1000; Converter_DCDC_CUI_P78E-1000_THT; mpn P78E12-1000

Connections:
+5V: C2.1, D4.2 (A), J6.1, J7.11, J7.12, J8.11, J8.12, U1.3 (Vout)
+12V: C4.1, C5.1, D2.2 (A), J3.1, J7.9, J7.10, J8.9, J8.10, U2.3 (Vout)
+15V: C1.1, C3.1, C6.1, D5.2 (A), F1.2, L1.1, TH1.1, U1.1 (Vin), U2.1 (Vin)
+VDC: J1.1, J2.1, J4.1, J5.1, JP1.1 (A), SW1.1 (A)
-12V: C7.2, C8.2, J3.2, J7.1, J7.2, J8.1, J8.2, R2.1, U3.2 (GND)
/CV: J7.13, J7.14, J8.13, J8.14
/GATE: J7.15, J7.16, J8.15, J8.16
GND: C1.2, C2.2, C3.2, C4.2, C5.2, C6.2, C7.1, C8.1, C9.2, D3.2 (A), H1.1, H2.1, H3.1, H4.1, J1.2, J2.2, J4.2, J5.2, J6.2, J7.3, J7.4, J7.5, J7.6, J7.7, J7.8, J8.3, J8.4, J8.5, J8.6, J8.7, J8.8, R1.2, R3.2, R4.2, TH1.2, U1.2 (GND), U2.2 (GND), U3.3 (Vout)
unnamed: C9.1, L1.2, U3.1 (Vin)
unnamed: D1.1 (K), F1.1
unnamed: D1.2 (A), JP1.2 (B), SW1.2 (B)
unnamed: D2.1 (K), R1.1
unnamed: D3.1 (K), R2.2
unnamed: D4.1 (K), R3.1
unnamed: D5.1 (K), R4.1

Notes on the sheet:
DC output
I(rated): 500 mA I(max): ~1A ripple: 75 mVp-p
5V converter
±12V converters
TH1 MOV optional Cut JP1 to use external power switch
15 to 20 VDC
DC input
Mounting holes
+12V I(rated): 1 A +12V I(max): ~1.5 A +12V ripple: 75 mVp-p -12V I(rated): 300 mA -12V I(max): ~900mA -12V ripple: 75 mVp-p
LEDs
Circuit protection

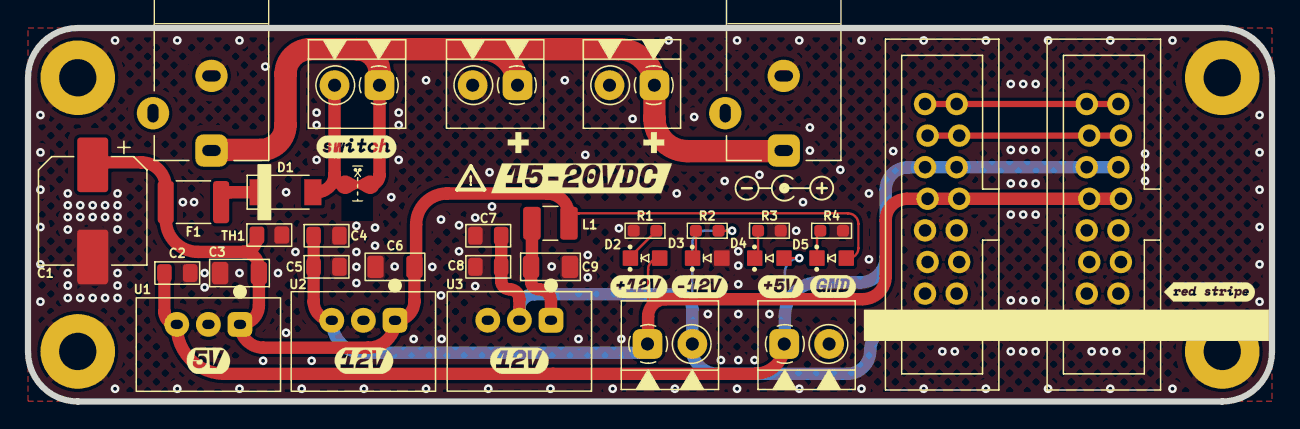
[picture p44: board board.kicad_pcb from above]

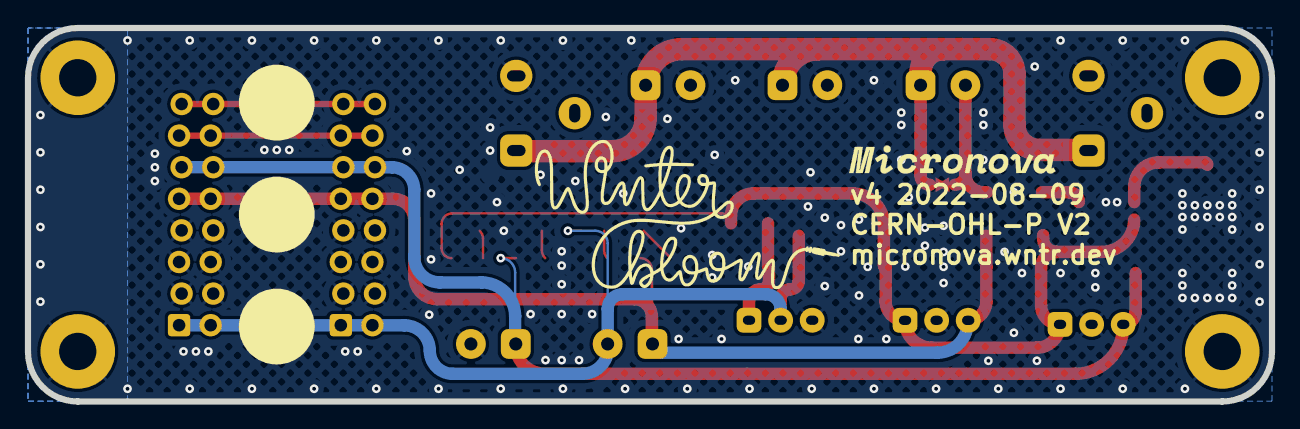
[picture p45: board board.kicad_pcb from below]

Board: 2 copper layers, 100.0 x 30.0 mm, 41 parts (2 on the bottom side), 15 nets.

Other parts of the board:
OSHW: OSHW-Logo_5.7x6mm_Copper
POLARITY: Symbol_Barrel_Polarity
WNTR: LOGO

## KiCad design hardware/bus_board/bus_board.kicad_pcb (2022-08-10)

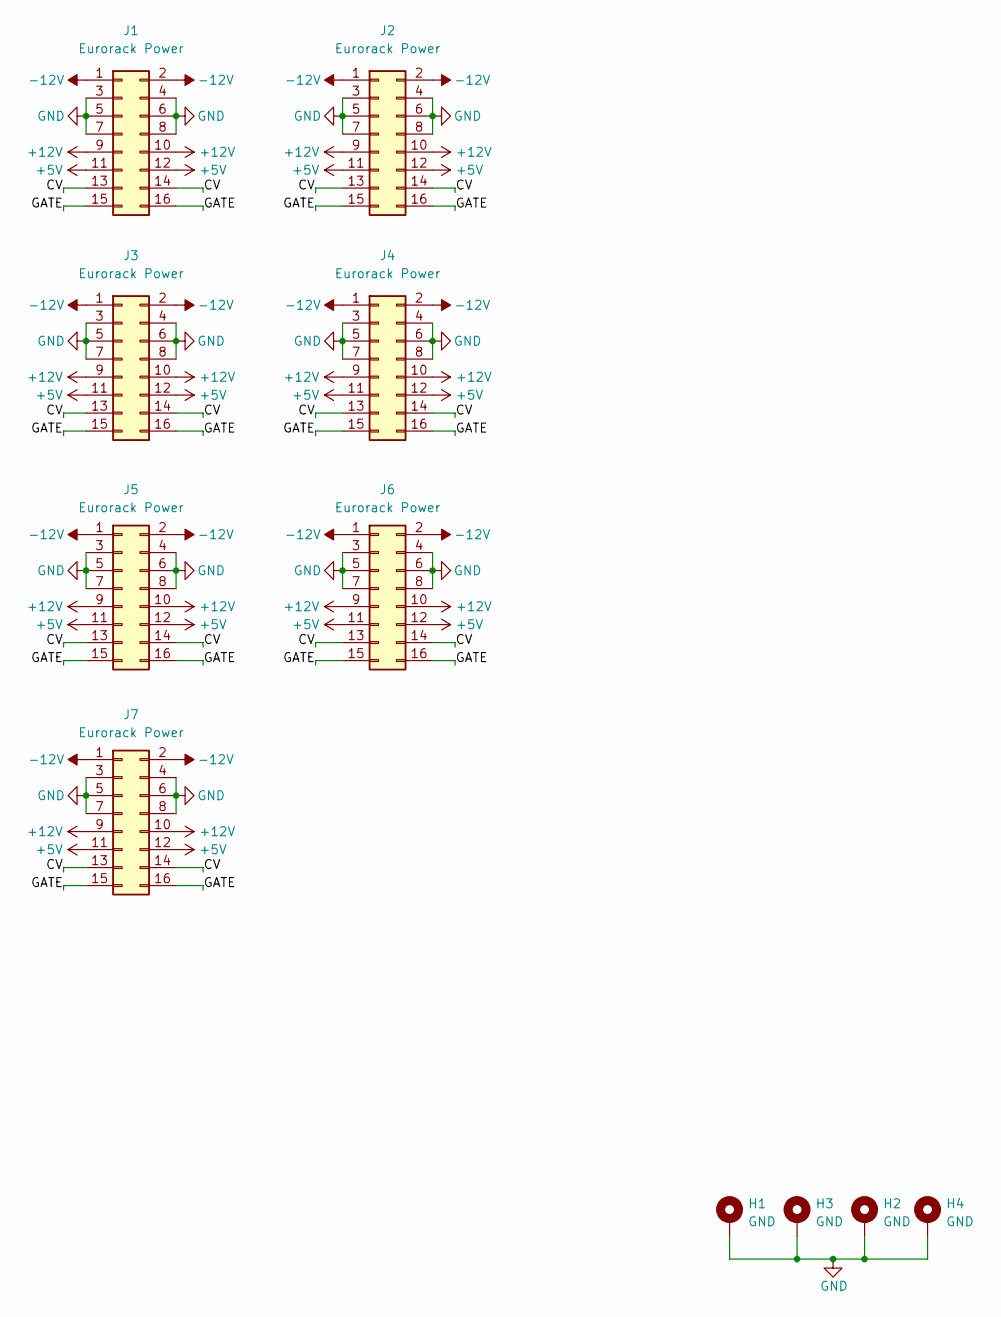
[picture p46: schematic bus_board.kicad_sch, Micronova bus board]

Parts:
H1, H2, H3, H4: GND; MountingHole_3mm_Pad
J1, J2, J3, J4, J5, J6, J7: Eurorack Power; Eurorack_Power_2x8_Shrouded_Lock; mpn 61201621621

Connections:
+5V: J1.11, J1.12, J2.11, J2.12, J3.11, J3.12, J4.11, J4.12, J5.11, J5.12, J6.11, J6.12, J7.11, J7.12
+12V: J1.9, J1.10, J2.9, J2.10, J3.9, J3.10, J4.9, J4.10, J5.9, J5.10, J6.9, J6.10, J7.9, J7.10
-12V: J1.1, J1.2, J2.1, J2.2, J3.1, J3.2, J4.1, J4.2, J5.1, J5.2, J6.1, J6.2, J7.1, J7.2
/CV: J1.13, J1.14, J2.13, J2.14, J3.13, J3.14, J4.13, J4.14, J5.13, J5.14, J6.13, J6.14, J7.13, J7.14
/GATE: J1.15, J1.16, J2.15, J2.16, J3.15, J3.16, J4.15, J4.16, J5.15, J5.16, J6.15, J6.16, J7.15, J7.16
GND: H1.1, H2.1, H3.1, H4.1, J1.3, J1.4, J1.5, J1.6, J1.7, J1.8, J2.3, J2.4, J2.5, J2.6, J2.7, J2.8, J3.3, J3.4, J3.5, J3.6, J3.7, J3.8, J4.3, J4.4, J4.5, J4.6, J4.7, J4.8, J5.3, J5.4, J5.5, J5.6, J5.7, J5.8, J6.3, J6.4, J6.5, J6.6, J6.7, J6.8, J7.3, J7.4, J7.5, J7.6, J7.7, J7.8

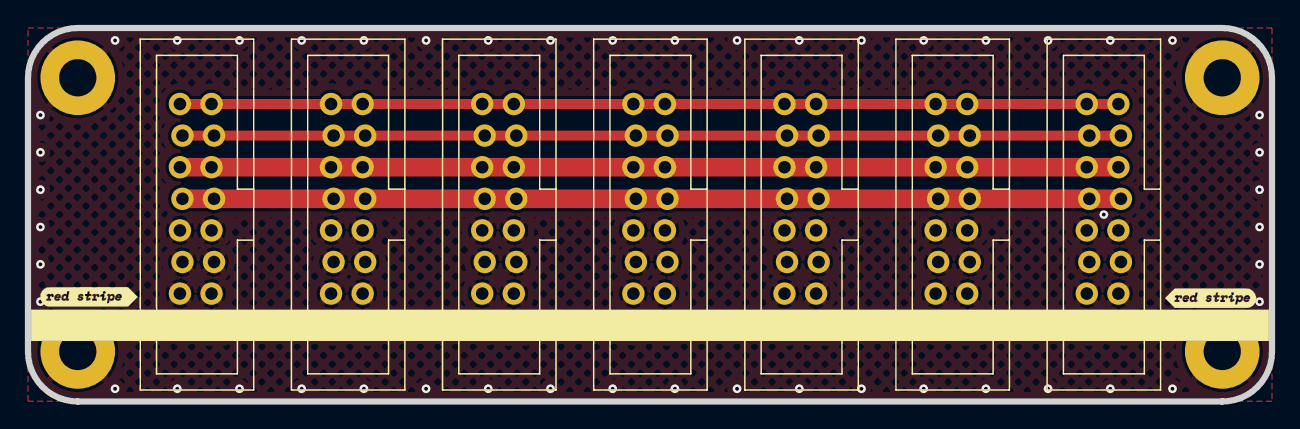
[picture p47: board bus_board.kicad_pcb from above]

Board: 2 copper layers, 100.0 x 30.0 mm, 12 parts (1 on the bottom side), 6 nets.

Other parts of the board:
OSHW: OSHW-Logo_5.7x6mm_Copper

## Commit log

2022-05-23 Add initial hardware design
    [board.kicad_pcb, board.kicad_sch]
2022-05-23 Update page details in schematic
    [board.kicad_sch]
2022-05-23 Use new winterbloom footprints
    [board.kicad_pcb, board.kicad_sch]
2022-05-28 Update some MPNs
    [board.kicad_sch]
2022-06-05 Add OSHW and polarity symbols to the PCB
    [board.kicad_pcb]
2022-06-05 Resolve ERC errors related to non-schematic footprints
    [board.kicad_pcb]
2022-06-14 Use hatched fills
    [board.kicad_pcb, board.kicad_sch]
2022-06-14 Add passive bus board
    [bus_board.kicad_pcb, bus_board.kicad_sch]
2022-06-20 Move some silkscreen around just a little
    [board.kicad_pcb, bus_board.kicad_pcb]
2022-07-31 Update schematic with new name and organize it a little
    [board.kicad_sch]
2022-07-31 Update the PCB with the new name
    [board.kicad_pcb, board.kicad_sch]
2022-07-31 Update the busboard with new name
    [bus_board.kicad_pcb, bus_board.kicad_sch]
2022-08-04 Widen some traces
    [board.kicad_pcb]
2022-08-04 Widen some traces- again
    [board.kicad_pcb, bus_board.kicad_pcb]
2022-08-10 hardware: various updates (v4)
    - switched to winterbloom footprints for caps and resistors
    - use fancytext labels
    [board.kicad_pcb, board.kicad_sch]
2022-08-10 hardware: use fancytext labels on busboard
    [bus_board.kicad_pcb, bus_board.kicad_sch]
2022-08-13 Add some helpful dimensions
    [board.kicad_pcb]
2022-09-02 Add PDF of schematic
2022-09-03 Fixup some MPNs
    [board.kicad_sch]
2024-04-07 user guide: switch to wintersong theme
2025-01-30 hardware: Added faceplate
    [faceplate.kicad_pcb]

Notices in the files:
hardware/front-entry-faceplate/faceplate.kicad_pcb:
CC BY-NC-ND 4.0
